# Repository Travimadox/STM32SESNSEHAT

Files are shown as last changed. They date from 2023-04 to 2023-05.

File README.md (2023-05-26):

# Imperium Environmental Monitoring HAT

The Imperium Environmental Monitoring HAT is a cutting-edge hardware accessory designed for use with STM32 microcontrollers. It is tailored for environmental monitoring and equipped with high-precision sensors for temperature and light. This allows for accurate data collection in various applications, including weather monitoring, room temperature monitoring, and greenhouse monitoring, providing invaluable insights into environmental conditions.

ImperiumSenseHAT
## Features

- High-precision sensors for temperature, humidity, atmospheric pressure, and light
- Seamlessly integrates into various systems
- Customizable to fit the needs of each user
- Easily programmable for extra functionality
- Affordable and reliable

## Usage

The Imperium Environmental Monitoring HAT can be used for a variety of purposes, including:

- Weather monitoring
- Room temperature and humidity monitoring
- Greenhouse monitoring

In addition, the sensor data can be used to make critical decisions about controlling external devices, such as triggering a fan or heater, to maintain a comfortable environment.

## Getting Started

To get started with the Imperium Environmental Monitoring HAT, simply connect it to your STM32 microcontroller using the provided pins. Then, download our library and follow the included instructions to begin collecting data.
- Hello World version of our board can be found here: [Hello World](HELLOWORLD.md)
- Detailed set-up instructions can be found here: [Setup](SESNSEHATSETUP.md)

## Customization

The Imperium Environmental Monitoring HAT is easily programmable, allowing the end user to add extra functionality to suit their specific needs. The provided libraries in the firmware folder includes examples of how to use the sensors.

## Cost

At Imperium, we pride ourselves on providing innovative and cost-effective solutions. Our HAT is a reliable and affordable option for anyone looking to monitor and control environmental conditions, whether in a commercial or personal setting.

## Support

If you have any questions or issues with the Imperium Environmental Monitoring HAT, please contact our support team at imperiumuct@gmail.com.

## License

This project is licensed under the [MIT License](LICENSE).

© 2023 Rumbizdai Mashumba, Phomolo Makina, and Travimadox Webb.

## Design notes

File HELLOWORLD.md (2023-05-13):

# STM32 ENVIRONSENSING HAT: Hello World Version

This program is designed to read data from temperature sensors and an analog light sensor, timestamp the data, and transmit it over UART to a terminal.

## Hello World Set Up Instructions

### Step 1: Hardware and Software Setup
For an in-depth guide on how to setup your hardware and software, kindly visit this link: [Setup Guide](SESNSEHATSETUP.md).

### Step 2: Download the HelloWorld Drivers
You can find and download the necessary HelloWorld drivers for this project from the following link: [HelloWorldDrivers](https://github.com/Travimadox/STM32SESNSEHAT/blob/main/Firmware/SENSEHATHELLOWORLD.zip)

### Step 3: Import the Project into STM32 CubeIDE
If you're unsure of how to import the project, refer to the following guides:
- [Imperium: Importing projects into STM32CubeIDE workspace - Step 3](https://github.com/Travimadox/STM32SESNSEHAT/blob/main/SESNSEHATSETUP.md)
- [Fastbitlab: Importing projects into STM32CubeIDE workspace](https://fastbitlab.com/microcontroller-embedded-c-programming-importing-projects-in-to-stm32cubeide-workspace/)

### Step 4: Build, Debug, and Flash the Project
Build and debug the project, then flash it onto the microcontroller. Remember to set the time and date at the beginning.

### Step 5: Setup Software Terminal Emulator
Open your software terminal emulator and ensure the settings match the UART settings in the hello world project. When everything is set up correctly, you should see output resembling the one below:

Hello World Output

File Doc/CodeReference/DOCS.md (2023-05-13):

# Code Reference

A web version of the doxumentation can be found here: [Imperium-STM32-SenseHat-Code-Reference](https://imperiumstm32hatdocs.tiiny.site/index.html)

A more detailed version of the documentation can also be found here: [Imperium-STM32-SenseHat-Code-Reference-Detailed](https://gleaming-capybara-68341f.netlify.app/files.html)
)

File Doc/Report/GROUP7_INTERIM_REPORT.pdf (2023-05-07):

## IMPERIUM

## STM32SenseHAT

### Title – STM32SenseHAT Report [EN]

Authors:

Rumbizdai Mashumba
Phomolo Makina
Travimadox Webb

MSHRUM006@myuct.ac.za
MKNPHO002@myuct.ac.za
WBBTRA001@myuct.ac.za

### Group 7 ♣

SenseHAT | Imperium

## Contents

1 Executive Summary | 3
2 Introduction | 3
3 Specifications | 5
4 Power Budget | 16
5 Design Process | 18
6 Conclusion | 19
Group7 | 1 | EEE3088F

Appendices | 21

## List of Tables

1 | Specifications of Battery Charger Submodule | | 5
2 | Specifications of the Battery protection submodule | | 6
3 | Specifications of the Voltage Regulator Submodule | | 7
4 | Specifications of the Microcontroller Board | | 9
5 | Specifications of the EEPROM | 10
6 | Specifications of the USB-UART Interface | 11
7 | Specifications of the Temperature Sensor | 13
8 | Specifications of the Light Sensor | 13
9 | Specifications of the Light-Dependent Resistor | 14
10 | Power Module Power Pudget | 16
11 | Microcontroller Module Power Budget | 17
12 | Sensing Module Power Budget | 17
13 | SenseHAT Power Consumption | 17

## List of Figures

1 | SenseHAT Block Diagram | | 4
2 | Power Submodule Schematic | | 8
3 | MCU Module Schematic | 12
4 | Sensing Module Schematic | 15
Group7 | 2 | EEE3088F

## 1 Executive Summary

The STM32 EnviroSensing HAT is a sophisticated, multi-purpose sensing system designed to accurately measure, log, and transmit various environmental parameters. The system comprises three primary modules: Power, MCU, and Sensing, each of which is meticulously designed to ensure optimal performance and seamless integration.
The Power module controls the MCU and sensors’ battery management, voltage regulation, and power distribution. It comprises a lithium-ion battery charger submodule that uses the TP4056 chip for precise charging control, a battery protection submodule incorporating the DW01 protection IC and dual MOSFETs for overcharge, over-discharge, and short-circuit protection, and a voltage regulator submodule utilizing the MCP1700T-3302ETT linear regulator for efficient voltage conversion.
The MCU module, built around the powerful and energy-efficient STM32F030F051C6T6 microcontroller, serves as the core processing unit. It is accompanied by an EEPROM (AT24C32) for non-volatile data storage, and multiple communication interfaces, including I2C, SPI, and UART, for seamless sensor data retrieval and transmission.
The Sensing module employs three high-precision sensors for direct interaction with the environment: a TMP102 temperature sensor with ±0.5°C accuracy and 12-bit resolution, an LTR-303-ALS digital light sensor providing 0.01 lux to 64k lux dynamic range with a 16-bit ADC, and an LDR (Light Dependent Resistor) for measuring ambient light levels. These sensors are carefully selected to ensure accuracy and compatibility with the overall system.

## 2 Introduction

### 2.1 SenseHat Concept

The STM32 EnviroSensing HAT is a custom-designed, innovative solution that accurately and responsively senses environmental conditions in various applications, including home environmental monitoring, greenhouse climate control, and industrial automation systems. By incorporating both temperature and light monitoring capabilities, this advanced HAT (Hardware Attached on Top) empowers users to effectively manage and regulate critical parameters. Seamlessly integrating temperature monitoring with ambient light sensing functionality, the STM32 EnviroSensing HAT ensures comprehensive environmental data collection. This combination of features is particularly useful in scenarios where maintaining optimal conditions is crucial, such as providing the perfect growing environment in a greenhouse. Additionally, the system can be implemented in smart home applications, offering adaptive temperature and lighting control based on real-time environmental data.
Key Sensor Specifications include a temperature sensor with a resolution of 0.0625, an accuracy of 0.5%, and a measurement range of -40°C to 125°C. The ambient light sensor boasts a 16-bit ADC resolution, an accuracy of 2%, and a detection range from 0.1 lux to 64k lux. The HAT is powered by a 5V bus for battery charging and a 3.3V bus to supply power to the MCU and sensors. Communication interfaces include I2C for effortless sensor and EEPROM communication with the STM32 and UART for efficient data transmission to the host computer. Data logging is a significant feature of the STM32 EnviroSensing HAT, with a consistent format that allows for easy analysis and integration into other systems. The logged data can
Group7 | 3 | EEE3088F

trigger user-defined threshold-based actions such as temperature and light regulation, further enhancing the device’s functionality.
In summary, the STM32 EnviroSensing HAT is a reliable and versatile environmental monitoring and control solution, making it ideal for a wide range of applications that require accurate and responsive sensing of temperature and light conditions.

### 2.2 Block Diagram

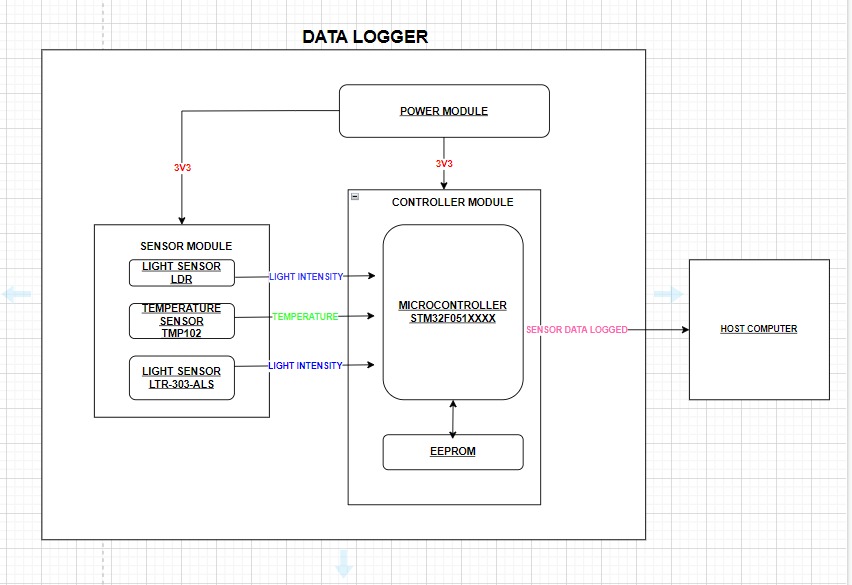
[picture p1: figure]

Figure 1: SenseHAT Block Diagram

Group7 | 4 | EEE3088F

## 3 Specifications

### 3.1 Power Module

The power module is designed to handle battery management and supply a stable 3.3V power source to all sensors and the MCU module from a 5V input provided by a USB bus.

### 3.1.1 Battery Charger Submodule

The battery charger submodule is responsible for managing the charging process for the 18650 battery. The specifications for this submodule are as follows: The chip used:TP4056

Table 1: Specifications of Battery Charger Submodule

Specification | Description/Detail
Input Voltage | VCC: 0.3-10 V TEMP,CE: 0-10 V
Charging current | 1000mA
Charge Voltage | 4.2V
Accuracy | 1.5%
Trickle Charge threshold | 2.9V
BAT Short Circuit duration | Continuous
BAT pin current | 1200mA
PROG pin current | 120uA
Operating Temperature | -45-85°C
Charge Status | Charging: RED LED-ON, GREEN-OFF Charge Termination: RED LED-OFF, GREEN-ON

Design Notes

1. Package: SOP-8
2. Rprog of 10k was used thus ibat is 130mA. This might be improved by changing the Rprog.
Group7 | 5 | EEE3088F

### 3.1.2 Battery protection submodule

This module protects the battery from under voltage, overvoltage, overcharging and overcurrent. Specifications are shown below: The chip used:DW01A

Table 2: Specifications of the Battery protection submodule

Specification | Detail
Input Voltage | 0.3-10V
Supply current | 3.0-6uA
OC output pin voltage | -24-0.3V
OD Output Pin Voltage | -0.-0.3V
CS Input pin voltage | -24-0.3V
Operating temperature range | -40-85°C
Starting charger Volatge | 1.2V
Overcharge Protection Voltage | 4.25-4.35V
Overcharge Release Voltage | 4.05-4.15V
Over-discharge Protection Voltage | 2.40-2.60 V
Overcurrent Protection Voltage | 130-170mV
Short current protection Voltage | 0.82-1.75V
Overcharge delay time | ”Typ:100ms Max 200ms”
Over-discharge delay time | ”Typical 55ms Maximum 200ms”
Overcurrent Delay Time | ”Typical 7ms Maximum 20ms”

Design Notes

1. Package: SOT-23-6
Group7 | 6 | EEE3088F

### 3.1.3 Voltage Regulator Submodule

This module regulates 5V from the USB bus/battery to 3.3V, suitable for the MCU and sensor module. Its specifications are shown below: The chip used:MCP1700T-3302ETT

Table 3: Specifications of the Voltage Regulator Submodule

Specification | Detail
Input Voltage | 2.3-6V
Input Quiescent Cur-rent | 1.6uA
Maximum Output Current | 250mA
Output Short Circuit Current | 408mA
Output Voltage Regu-lation | ”Min VR - 3.0%, VR - 2.0% Typ VR ± 0.4%, Max VR + 3.0%, VR + 2.0%”
VOUT Temperature Coefficient | 50 ppm/°C
Line Regulation | ”Min -1.0%, Typ 0.75%, Max 1%”
Load Regulation | ”Min -1.5%, Typ 1%, Max 1.5%”
Dropout Voltage | 350mV
Output Noise | 3 µV/(Hz)1/2
Power Supply Ripple Rejection Ratio | 44dB
Thermal Shutdown Protection | 140°C

Design Notes

1. Package: SOT-23-6
2. Voltage Regulator (VR): 3.3V
3. The internal power dissipation of the MCP1700 voltage regulator is a function of input voltage, output voltage, and output current. The power dissipation from the quiescent current draw is negligible, given its low value of 1.6 µA multiplied by the input voltage (VIN). The following equation can be employed to calculate the internal power dissipation of the LDO:1.6µA × VIN
Group7 | 7 | EEE3088F

### 3.1.4 Schematic

Link:https://github.com/Travimadox/STM32SESNSEHAT/blob/main/PCB/STM32SENSEHAT/power.kicad_sch (https://github.com/Travimadox/STM32SESNSEHAT/blob/main/PCB/STM32SENSEHAT/power.kicad_sch)

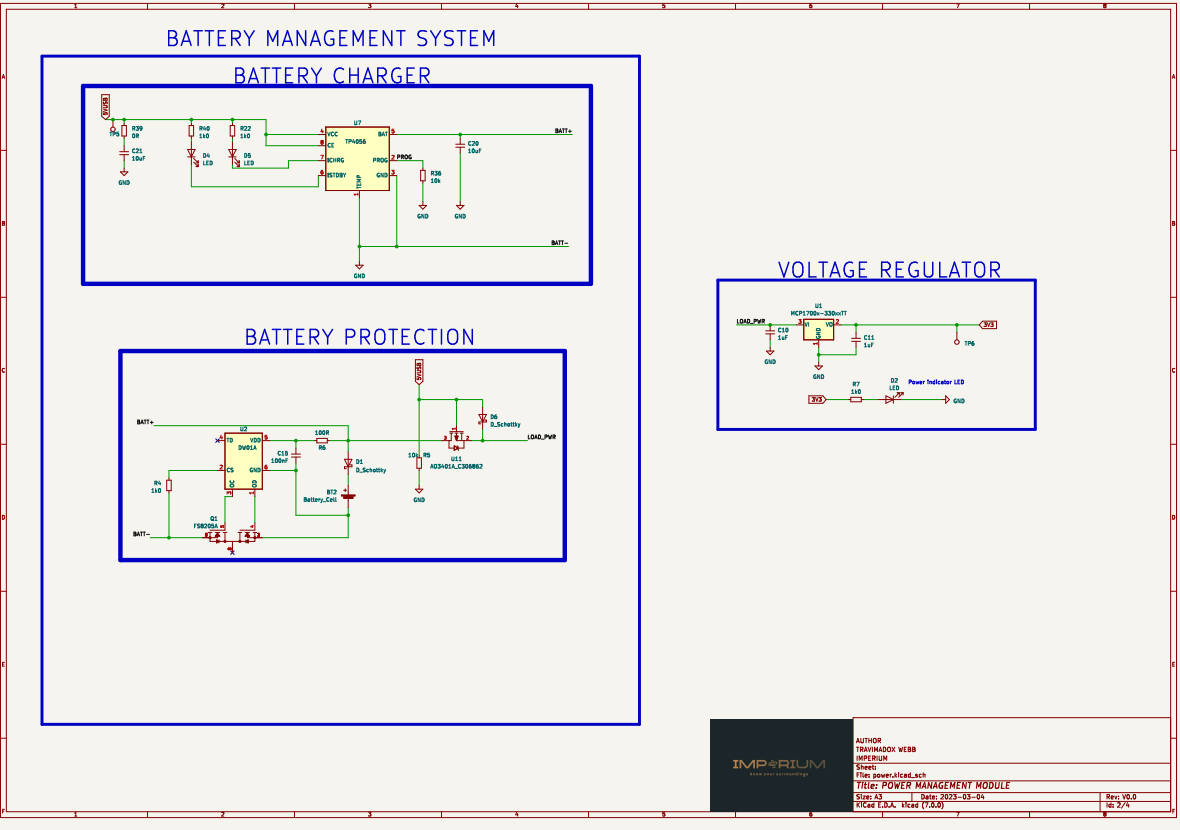
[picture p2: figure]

Figure 2: Power Submodule Schematic

### 3.1.5 Fit to Requirements

The current design meets the project requirements; however, there is potential for enhancements, particularly in the battery protection aspect. One possible improvement is modifying the battery charging mechanism. Adjusting the Rprog resistor can increase the charging current, eliminating the need to disconnect the battery when the USB is connected. This modification could streamline the charging process and provide a more user-friendly experience. Exploring this option and implementing it in future iterations of the STM32 EnviroSensing HAT could lead to a more refined and efficient design.

Group7 | 8 | EEE3088F

### 3.2 Microcontroller Module

The microcontroller interfacing submodule manages the communication between the microcontroller and the other components of HAT. It uses an STM32F0 microcontroller as the core processing unit, providing stable and efficient performance.

### 3.2.1 Microcontroller submodule

Its specifications are shown below: The chip used:STM32F051C6T6

Table 4: Specifications of the Microcontroller Board

Specification | Detail
Input Voltage Range | 2.6V- 3.3V
Standard Operational Voltage | ”Minimum: 2V Maximum: 3.6V”
External main voltage supply | ”Minimum: -0.3V Maximum: 4.0V”
Backup Operational Voltage | ”Minimum: 2.4V Maximum: 3.6V”
Input current | ”Minimum- 0.5 uA Maximum-5mA”
MCU Family | STM32F051C6TX
External memory | Include an EEPROM to store data from sensors
Real-time clock | Includes an RTC for timestamping data
Internal Clock Frequency | Typically: 8MHz
Data logging | Automatically logs data when USB is plugged into a computing device, with specified transmission times and time-outs in case of sensor errors or missed data
Sensor interface | Interfaces with digital sensors through I2C and ADCs with GPIO pins
Operating Temperature | ”Minimum- -40°C Maximum- 105 oC”
Storage Temperature Range | -65°C to 150°C
Flash Memory | 32 KB
RAM | ”32 KB Includes flash memory”
Clock Speed | Minimum- 48 MHz
Supported communication proto-cols | MCU should have interfaces of UART, I2C or SPI
Group7 | 9 | EEE3088F

Design notes

1. Package: LQFP48
2. The MCU in the STM32 EnviroSensing HAT is designed with additional headers to facilitate connections with external devices not included on the board. This feature provides increased flexibility and expandability, enabling users to interface with various peripherals for extended functionality and customisation options.

### 3.2.2 Memory Module

The AT24C256C-SSHL-T EEPROM is utilised in the STM32 EnviroSensing HAT for reading and writing logged data. This memory module’s specifications ensure efficient data storage and retrieval, catering to the project’s requirements. The following are the key specifications of the AT24C256C-SSHL-T EEPROM:

Table 5: Specifications of the EEPROM

Specification | Detail
Input Voltage | 1.7-5.5V
Supply Current | ”Typ 1mA Max 2mA”
Standby current | ”Typ 1uA Max 6uA”
Interface | I2C
Compatibility | 400kHz (1.7V) and 1MHz (2.5V, 2.7V, 5.0V)
Page Size | 64-byte
Pages | 512
Endurance | 1,000,000 write cycles
Data retention | 40 years
Operating temperature | 55°C to +125°C
DC Output Current | 5.0mA
Self-timed write cycle | 5ms

Design Notes

1. Package: SOIC-8
2. The address of the EEPROM in the STM32 EnviroSensing HAT is set to the default configuration, as pins A0, A1, and A2 are grounded. Zero-ohm resistors are connected to the communication lines as a mechanism for error handling, enabling the lines to be disconnected in case of unprecedented errors. This design aspect ensures flexibility in addressing potential issues related to data transmission within the EnviroSensing HAT.
Group7 | 10 | EEE3088F

### 3.2.3 Communications with Host Computer

The FT234 chip is incorporated in the STM32 EnviroSensing HAT to manage data transmission between the board and the host computer. This FTDI chip transmits logged data to the user, ensuring efficient and reliable communication. The key specifications of the FT234 chip are as follows:

Table 6: Specifications of the USB-UART Interface

Specification | Detail
Input Voltage | 5V
Data transfer rate | 300 baud to 3 Mbaud
UART interface | ”7 or 8 data bits, 1 or 2 stop bits and odd / even / mark/space / no parity UART signal inversion option *Synchronous and asynchronous bit bang interface options with RD# and WR# strobes.”
Driver Support | ”Royalty-free VIRTUAL COM PORT (VCP) DRIVERS Royalty-free D2XX Direct Drivers (USB Drivers + DLL S/W Interface) Refer to http://www.ftdichip.com/Documents/InstallGuides.htm” (http://www.ftdichip.com/Documents/InstallGuides.htm)
Operating Tempera-ture (Power Applied) | -40°C to 85°C
VCC Supply Voltage | -0.3 to +5.5
VCCIO IO Voltage | 0.3 to +4.0
DC Input Voltage – USBDP and USBDM | -0.5 to +3.63
DC Output Current – Output | 22mA
Data Retention | 10 years
Write Cycle | 2000 cycles
Read Cycle | Unlimited Cycles

Design Notes

1. Package: DFN-12
2. The STM32 EnviroSensing HAT utilises a USB self-powered configuration for a reliable power supply. A ferrite bead is incorporated to mitigate electromagnetic interference (EMI) and enhance signal integrity. These design aspects contribute to the HAT’s efficient operation and performance stability.
Group7 | 11 | EEE3088F

### 3.2.4 Schematic

Link:https://github.com/Travimadox/STM32SESNSEHAT/blob/main/PCB/STM32SENSEHAT/mcu.kicad_sch (https://github.com/Travimadox/STM32SESNSEHAT/blob/main/PCB/STM32SENSEHAT/mcu.kicad_sch)

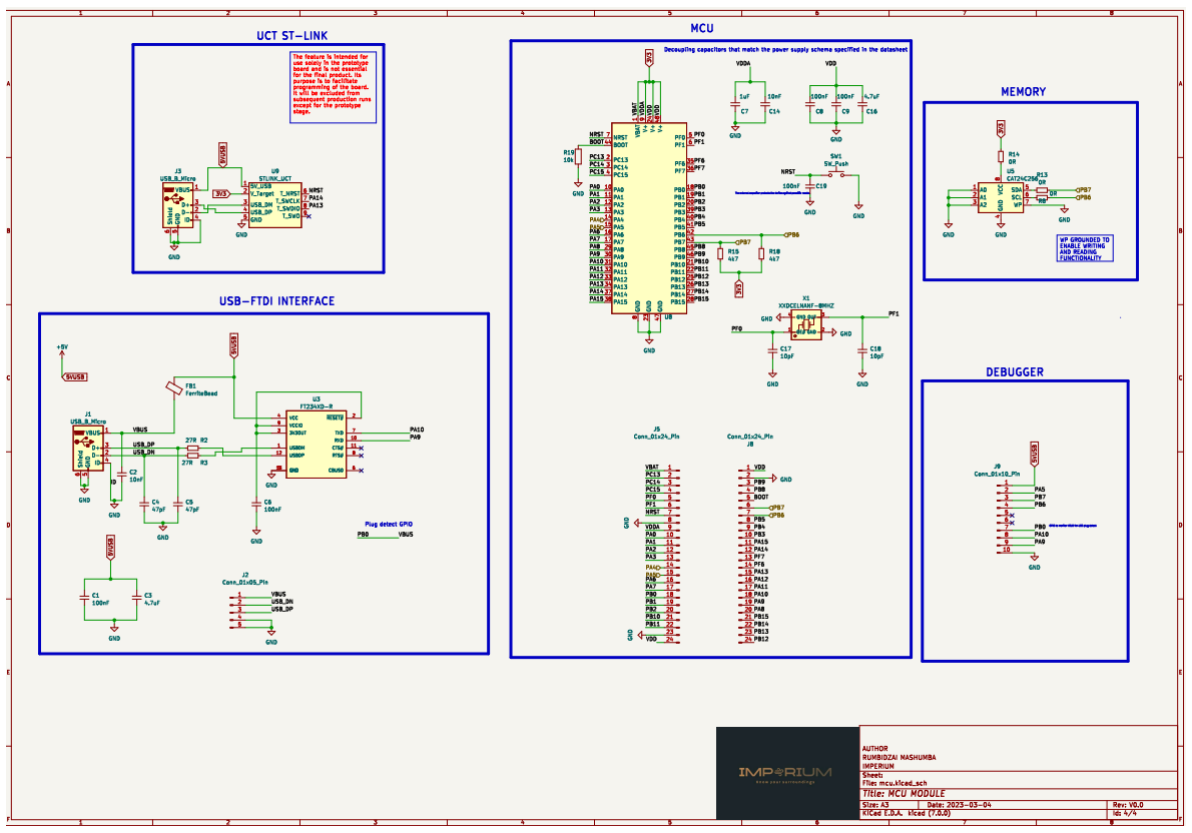
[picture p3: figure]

Figure 3: MCU Module Schematic

### 3.2.5 Fit to Requirements

The current design of the MCU module meets the basic requirements set forth by the client. However, several improvements can be considered for future iterations. For example, replacing the EEPROM with a higher-capacity variant or configuring the memory to use an SD card would enable longer data logging periods. Integrating an ESP32 module could also provide network connectivity for wireless data transmission and battery-level alerts. Furthermore, incorporating a dedicated CMOS battery for the internal RTC in the STM32 would prevent loss of time settings in the event of power loss. These enhancements would further refine the MCU module and expand its capabilities.

Group7 | 12 | EEE3088F

### 3.3 Sensing Module

Responsible for interacting with the environment directly and sensing environmental data

### 3.3.1 Temperature sensor

The temperature sensor used is TMP102. Its specifications are:

Table 7: Specifications of the Temperature Sensor

Specification | Details
Input Voltage | 3.3V
Range | –40°C to 125°C
Accuracy (tempera-ture error) | ”–25°C to 85°C ±0.5 –40°C to 125°C ±1”
Resolution | 0.0625
Operating tempera-ture | –55°C to 150°C
Interface | ”I2C Supports High Speed and Fast Mode”

Design Notes

1. Package: SOT-563
2. The alert pin is not connected in the current schematic, which may constrain certain chip functionalities. However, this design choice’s core purpose of temperature measurement remains unaffected. Future iterations could consider wiring the alert pin to enhance the chip’s overall capabilities without compromising the basic functionality.

### 3.3.2 Light Sensor

The sensor used is the LTR-303-ALS. The specifications are as follows:

Table 8: Specifications of the Light Sensor

Specification | Details
Input Voltage | 3.3V
Operating tempera-ture | –30°C to 70°C
Full dynamic range | 0.01lux-64k lux
Effective Resolution | 16 bits
Interface | ”I2C Supports fast Mode”
Group7 | 13 | EEE3088F

Design Notes

1. Package: SOT-363
2. In the current schematic, the alert pin is not connected, potentially limiting some of the chip’s features, though the basic functionality of ambient light measurement remains unaffected. The power pin of this chip is designed to be connected to Vcc only in the event of a TMP102 sensor failure. It should be noted that the sensor accuracy for this particular component is not explicitly stated in the datasheet. Future design iterations may address these aspects to optimize the chip’s functionality.

### 3.3.3 LDR

An LDR (light-dependent resistor) has been incorporated into the design to supplement the digital light sensor, enhancing the system’s overall light-sensing capabilities. The specifications of the LDR are as follows:

Table 9: Specifications of the Light-Dependent Resistor

Specification | Details
Input Voltage | ”Typical:3.3V Maximum:10V”
Maximum Power Dissipation | 90mW
Ambient Temperature | -30°C to 70°C
Spectral Peak | 540nm
Light resistance | 10-20k Ω
Dark resistance | 2MΩ
Gamma Value | 0.7
Response Time | ”Rise Time: 30ms Decay Time:30ms”

Design Notes

1. The LDR employed in this design is a basic photoresistor, specifically, the model widely used in the first-year practicals of the EEE1006F course at the University of Cape Town. Utilising a familiar and accessible LDR, the design aims to leverage the team’s existing knowledge and experience, ensuring ease of implementation and compatibility with other components.
Group7 | 14 | EEE3088F

### 3.3.4 Schematic

Link::https://github.com/Travimadox/STM32SESNSEHAT/blob/main/PCB/STM32SENSEHAT/sensor.kicad_sch

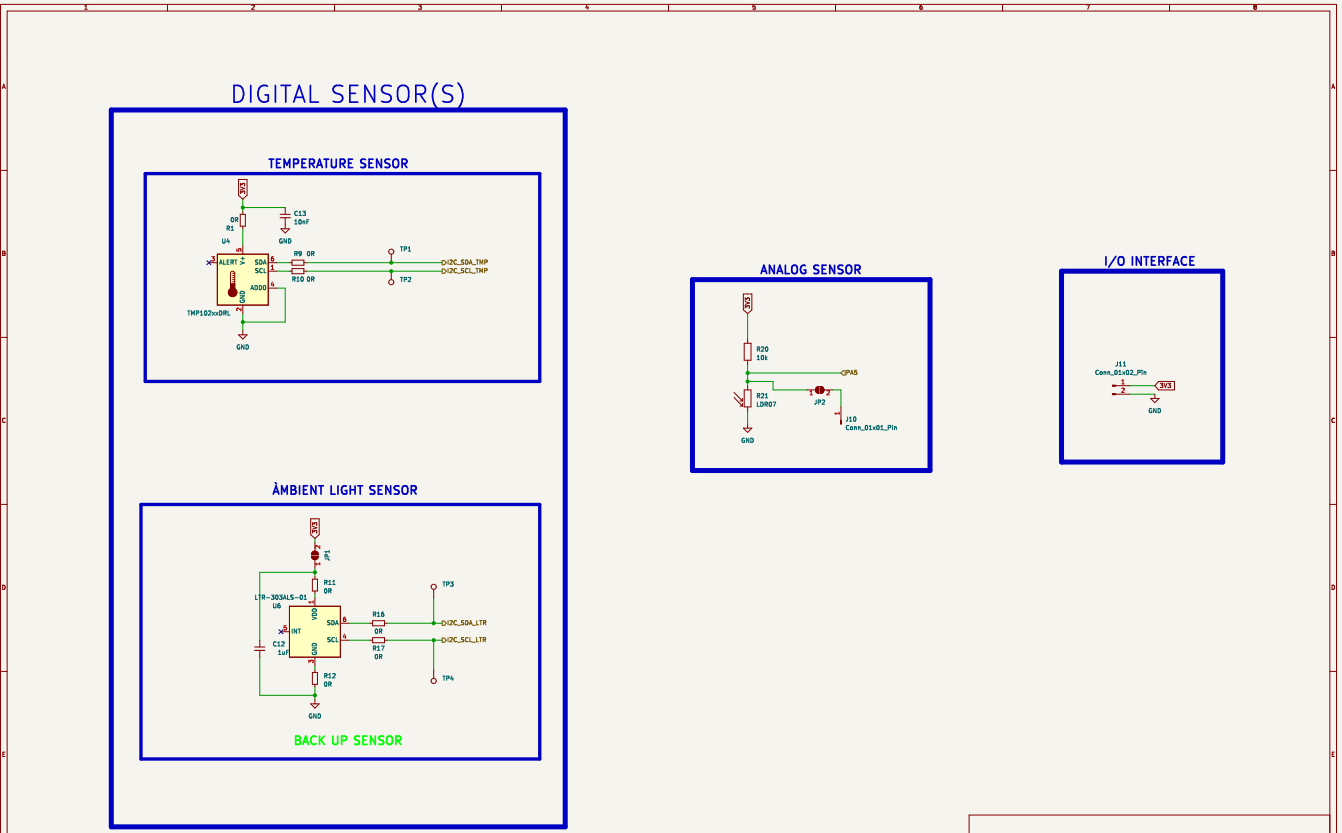
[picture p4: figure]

Figure 4: Sensing Module Schematic

### 3.3.5 Fit to Requirements

The current sensor configuration is suitable for the specified use cases; however, potential modifications could be considered for expanding functionality. Although the analog LDR may exhibit limited sensitivity (approx. 100 lux) and accuracy (±10%), it is sufficient for this board’s intended applications, such as basic ambient light monitoring. For higher lux ranges, the digital light sensor (LTR-303 ALS) with a range of 0.1 lux to 64,000 lux and an accuracy of ±2% should be utilised. The decision to leave the alert pins of the digital sensor unconnected also limits the sensor’s capabilities, such as interrupt-based alerts. Furthermore, the sensors remain powered on even when not recording data, leading to unnecessary power consumption, which could be up to 10% of the total power budget. Addressing this concern and implementing power-saving strategies, such as sleep mode or power gating, will be a priority in the next iteration of the board design—the board’s efficiency and overall performance.

Group7 | 15 | EEE3088F

## 4 Power Budget

### 4.1 Power Module

Table 10: Power Module Power Pudget

Component | Supply
| Voltage | Minimum
| | Current | Typical
| | | Current | Maximum
| | | | Current | Minimum
| | | | | Power | Typical
| | | | | | Power | Maximum
| | | | | | | Power
TP4056 | 5 | 0.95 | 1 | 1.05 | 4.75 | 5 | 5.25
DW01A | 3.6 | 0.000003 | 0.000003 | 0.000006 | 0.0000108 | 0.0000108 | 0.0000216
MCP1700X-330XXTT | 5 | 0.000016 | 0.000016 | 0.000004 | 0.00008 | 0.00008 | 0.00002
Resistors | | | | | 1 | 1 | 1
| | | | Total Power | 5.7500908 | 6.0000908 | 6.2500416

Notes:

1. For the DW01A and MCP1700X-330XXTT, minimum current values were not provided in the datasheets. Therefore, the typical current values were used in their place.
2. The power budget accounts for 8 resistors, each with a power rating of 125mW, for a total power dissipation of 1W.
3. Capacitors were not included in the power budget, as their power consumption was approximated to be negligible.
4. The ferrite bead is not included in the power budget. However, based on its specifications (300mA, 68nH ± 5%, 850mΩ, 0603 SMD, ROHS), its power consumption can be approximated using P = I

2R, where I is the current and R is the resistance.

5. The AO3401A MOSFET was not included in the power budget due to insufficient information in the datasheet. However, its rated specifications (20V, 6A, 1.5W, 23mΩ@4.5V) can be used to approximate power consumption using P = I

2R, where I is the drain
current and R is the on-resistance at the specified gate voltage.
6. The Schottky diode was not included in the power budget, as there was no direct power consumption information provided in the datasheet. However, based on its specifications (30V, 800mV@100mA, 200mA, SOT-23, ROHS), its power consumption can be estimated using P = IV , where I is the forward current and V is the forward voltage drop. Additionally, reverse recovery characteristics can be considered for dynamic power estimation.
Group7 | 16 | EEE3088F

### 4.2 Microcontroller Module

The power budget for the microcontroller interfacing module is shown below:

Table 11: Microcontroller Module Power Budget

Component

Supply
Voltage
(nominalV)

Minimum
Current

Typical
Current

Maximum
Current

Minimum
Power

Typical
Power

Maximum
Power
STM32F051C6T6 | 3.3 | 0.05 | 0.1 | 0.1 | 0.165 | 0.33 | 0.33
FT234XD-R | 3.3 | 0.0065 | 0.008 | 0.0083 | 0.02145 | 0.0264 | 0.02739
CAT24C256 | 3.3 | 0.001 | 0.001 | 0.002 | 0.0033 | 0.0033 | 0.0066
Resistors | | | | | 1 | 1 | 1
| | | | Total Power | 1.18975 | 1.3597 | 1.36399

Notes:

1. The power budget accounts for 8 resistors, each with a power rating of 125mW, for a total power dissipation of 1W.

### 4.3 Sensing Module

The power budget for the sensing module is shown below:

Table 12: Sensing Module Power Budget

Component

Supply
Voltage
(nominalV)

Minimum
Current

Typical
Current

Maximum
Current

Minimum
Power

Typical
Power

Maximum
Power
TMP102XXDRL | 3.3 | 0.000001 | 0.00001 | 0.00001 | 0.0000033 | 0.000033 | 0.000033
LTR-303ALS-01 | 3.3 | 0.000005 | 0.00022 | 0.00022 | 0.0000165 | 0.000726 | 0.000726
Resistors | | | | | 1 | 1 | 1
| | | | Total Power | 1.0000198 | 1.000759 | 1.000759

Notes:

1. The power budget accounts for 8 resistors, each with a power rating of 125mW, for a total power dissipation of 1W.

### 4.4 System Total

The system power budget is shown below:

Table 13: SenseHAT Power Consumption

Submodule | Minimum
| Power | Typical
| | Power | Maximum
| | | Power
Power Module | 5.7500908 | 6.0000908 | 6.2500416
Sensing Module | 1.0000198 | 1.000759 | 1.000759
MCU Module | 1.18975 | 1.3597 | 1.36399
Total | 7.9398606 | 8.3605498 | 8.6147906
Group7 | 17 | EEE3088F

## 5 Design Process

The design process for the STM32 EnviroSensing HAT was characterised by several critical decisions and inflexion points that ultimately shaped the final product. This section describes these vital moments, the rationale behind each choice, and supporting details and numbers.

### 5.1 Selection of Microcontroller

The STM32F051C6T6 was selected as the primary microcontroller due to its availability during design. This ARM Cortex-M0-based MCU features 32KB Flash memory, 4KB SRAM, and a 48MHz maximum frequency, ensuring compatibility with other microcontrollers from the same family if needed in the future.

### 5.2 Sensor Selection

Initially, the BME280 sensor was considered for its compactness and rich feature set. However, due to budget constraints, we opted for the more affordable TMP102 ($1.50/unit) and LTR-303 ALS ($0.65/unit) sensors as alternatives to the BME280 ($3.00/unit). This decision led to a slight reduction in accuracy compared to the BME280. It resulted in the loss of approximately 10% of the available board space, necessitating adjustments in the overall layout and component placement.

### 5.3 Choice of Power Supply Regulator

We selected Texas Instruments’ MCP1700 low-dropout (LDO) linear regulator for our design, considering its compatibility with our 5V supply, budget constraints, and performance requirements. The MCP1700 delivers a stable 3.3V output at up to 250mA with an input voltage range of 2.7V to 6V, providing a 1V headroom for voltage fluctuations. To ensure the MCP1700’s proper thermal performance, we calculated power dissipation and evaluated the junction-to-ambient thermal resistance, verifying that the maximum junction temperature would not be exceeded during operation. This approach allowed us to implement the MCP1700 effectively, meeting our project’s technical and budgetary requirements.

### 5.4 Data Storage and Retrieval

A 512KB (4Mbit) EEPROM, such as the CAT24C256 by Atmel, was utilised as the only available option for data storage during the design process. This capacity limits data collection to approximately two days before the EEPROM becomes full, assuming a data logging rate of one sample per second. Another reason for choosing the CAT24C256 was its low cost, at just $0.50 per unit, which further contributed to meeting the project’s budget constraints.

### 5.5 Communication Protocols

I2C was chosen as the primary communication protocol due to the team’s familiarity with I2C devices, facilitating firmware development. The FTDI FT234XD-R UART bridge chip was selected for data transmission to the host computer because of previous experience with the

Group7 | 18 | EEE3088F

component and project requirements. The FT234XD-R supports data transfer rates of up to 3 Mbaud, ensuring efficient communication between the STM32 EnviroSensing HAT and the host computer.

### 5.6 PCB Layout and Design

The PCB layout was iteratively improved to minimise signal interference, reduce electromagnetic noise, and enhance manufacturability. Critical component placement and proper heat dissipation were prioritised, utilising thermal vias and copper pour areas. The final PCB dimensions were 100mm x 100mm.

### 5.7 Testing and Debugging

Several simulations were performed to ensure the robustness of the design, including schematic Design Rule Checks (DRCs) and sensor testing with breakout boards, breadboards, and the STM32 microcontroller to validate the concept in real-world conditions. The testing involved measuring temperature and light levels under various environmental conditions to ensure accuracy and reliability.

### 5.8 ST-Link Inclusion

The decision to include the ST-Link debugger was debated until the last minute, and it was ultimately incorporated into the prototype board. The ST-Link V2 debugger has an SWD interface.

## 6 Conclusion

In conclusion, the STM32 EnviroSensing HAT is a highly capable and efficient board providing an excellent environmental sensing application platform. The current design meets the client’s basic requirements, and there is potential for further enhancements to expand the board’s capabilities.
The power module, battery charger submodule, battery protection submodule, voltage regulator submodule, MCU module, memory module, and sensing module have all been designed to meet the project’s specific requirements. The components’ specifications have been carefully considered to ensure optimal performance and efficient operation.
However, several areas for improvement have been identified in the design. For instance, modifying the battery charging mechanism by adjusting the Rprog resistor could streamline the charging process and provide a more user-friendly experience. Incorporating an ESP32 module could provide network connectivity for wireless data transmission and battery-level alerts. Power-saving strategies, such as sleep mode or power gating, could reduce unnecessary power consumption and enhance the board’s efficiency.
By refining these aspects and incorporating additional functionalities, the STM32 EnviroSensing HAT could become an even more capable platform for environmental sensing applications. The team is committed to further developing and refining the design, incorporating
Group7 | 19 | EEE3088F

user feedback and incorporating new technological advancements to ensure that the board remains a leading solution for environmental sensing.

Group7 | 20 | EEE3088F

# Appendices

Group7 | 21 | EEE3088F

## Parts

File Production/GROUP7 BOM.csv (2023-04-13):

Comment | Designator | Footprint | JLCPCB Part #
10nF | C2 | Capacitor_SMD:C_0805_2012Metric | C1710
1k0 | R22,R4,R7,R40 | Resistor_SMD:R_0805_2012Metric | C17513
USB_B_Micro | J1,J3 | footprints:USB_Conn_JLC_LCSC_C404969 | C404969
10uF | C20,C21 | Capacitor_SMD:C_0805_2012Metric | C15850
4k7 | R15,R18 | Resistor_SMD:R_0805_2012Metric | C17673
1uF | C12 | Capacitor_SMD:C_0805_2012Metric | C28323
27R | R2,R3 | Resistor_SMD:R_0805_2012Metric | C17594
MCP1700x-330xxTT | U1 | JLCfootprint:SOT-23-3_L2.9-W1.6-P1.90-LS2.8-BR | C39051
FT234XD-R | U3 | JLCfootprint:DFN-12_L3.0-W3.0-P0.45-BL-EP | C132158
4.7uF | C3 | Capacitor_SMD:C_0805_2012Metric | C1779
100nF | C1,C6,C15 | Capacitor_SMD:C_0805_2012Metric | C49678
FS8205A | Q1 | JLCfootprint:TSSOP-8_L4.4-W3.0-P0.65-LS6.4-BL | C5148694
AO3401A | U11 | JLCfootprint:SOT-23-3_L2.9-W1.3-P1.90-LS2.4-BR | C306862
CAT24C256 | U5 | JLCfootprint:SOIC-8_L4.9-W3.9-P1.27-LS6.0-BL | C6482
TMP102xxDRL | U4 | JLCfootprint:SOT-563_L1.6-W1.2-P0.50-LS1.6-BR | C99269
TP4056 | U7 | JLCfootprint:ESOP-8_L4.9-W3.9-P1.27-LS6.0-BL-EP | C382139
0R | R1,R16,R17,R39 | Resistor_SMD:R_0805_2012Metric | C17477
LTR-303ALS-01 | U6 | JLCfootprint:SOT-363_L2.0-W1.3-P0.65-LS2.1-BL | C364577
47pF | C4,C5 | Capacitor_SMD:C_0805_2012Metric | C14857
FerriteBead | FB1 | JLCfootprint:L0603 | C13415
10k | R5,R19,R20,R36 | Resistor_SMD:R_0805_2012Metric | C17414
100R | R6 | Resistor_SMD:R_0805_2012Metric | C17408
DW01A | U2 | JLCfootprint:SOT-23-6_L2.9-W1.6-P0.95-LS2.8-BL | C351410
XXDCELNANF-8MHZ | X1 | JLCfootprint:OSC-SMD_4P-L3.2-W2.5-BL | C518154
D_Schottky | D1,D6 | JLCfootprint:SOT-23-3_L3.0-W1.7-P0.95-LS2.9-BR | C47546

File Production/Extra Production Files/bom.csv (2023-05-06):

Designator | Footprint | Quantity | Value | LCSC Part #
BT2 | BatteryHolder_Keystone_1042_1x18650 | 1 | Battery_Cell
C1, C15, C6 | 805 | 3 | 100nF
C10, C11, C7 | C_Disc_D5.0mm_W2.5mm_P5.00mm | 3 | 1uF
C12 | 805 | 1 | 1uF
C13, C14 | C_Disc_D5.0mm_W2.5mm_P5.00mm | 2 | 10nF
C16 | C_Disc_D5.0mm_W2.5mm_P5.00mm | 1 | 4.7uF
C17, C18 | C_Disc_D5.0mm_W2.5mm_P5.00mm | 2 | 10pF
C19, C8, C9 | C_Disc_D5.0mm_W2.5mm_P5.00mm | 3 | 100nF
C2 | 805 | 1 | 10nF
C20, C21 | 805 | 2 | 10uF
C3 | 805 | 1 | 4.7uF
C4, C5 | 805 | 2 | 47pF
D1, D6 | SOT-23-3_L3.0-W1.7-P0.95-LS2.9-BR | 2 | D_Schottky
D2, D4, D5 | LED_D5.0mm | 3 | LED
FB1 | L0603 | 1 | FerriteBead
J1, J3 | USB_Conn_JLC_LCSC_C404969 | 2 | USB_B_Micro
J10 | PinHeader_1x01_P2.54mm_Vertical | 1 | Conn_01x01_Pin
J11 | PinHeader_1x02_P2.54mm_Vertical | 1 | Conn_01x02_Pin
J2 | PinHeader_1x05_P2.54mm_Vertical | 1 | Conn_01x05_Pin
J5, J8 | PinHeader_1x24_P2.54mm_Vertical | 2 | Conn_01x24_Pin
J9 | PinHeader_1x10_P2.54mm_Vertical | 1 | Conn_01x10_Pin
JP1 | SolderJumper-2_P1.3mm_Open_Pad1.0x1.5mm | 1 | SolderJumper_2_Open
JP2 | SolderJumper-2_P1.3mm_Open_RoundedPad1.0x1.5mm | 1 | SolderJumper_2_Open
Q1 | TSSOP-8_L4.4-W3.0-P0.65-LS6.4-BL | 1 | FS8205A
R1, R10, R11, R12, R13, R14, R16, R17, R39, R8, R9 | 805 | 11 | 0R
R15, R18 | 805 | 2 | 4k7
R19, R20, R36, R5 | 805 | 4 | 10k
R2, R3 | 805 | 2 | 27R
R21 | R_LDR_5.1x4.3mm_P3.4mm_Vertical | 1 | LDR07
R22, R4, R40, R7 | 805 | 4 | 1k0
R6 | 805 | 1 | 100R
SW1 | SW_PUSH_6mm | 1 | SW_Push
TP1, TP2, TP3, TP4, TP5, TP6 | TestPoint_Pad_D3.0mm | 6 | TestPoint
U1 | SOT-23-3_L2.9-W1.6-P1.90-LS2.8-BR | 1 | MCP1700x-330xxTT
U11 | SOT-23-3_L2.9-W1.3-P1.90-LS2.4-BR | 1 | AO3401A_C306862 | C306862
U2 | SOT-23-6_L2.9-W1.6-P0.95-LS2.8-BL | 1 | DW01A
U3 | DFN-12_L3.0-W3.0-P0.45-BL-EP | 1 | FT234XD-R
U4 | SOT-563_L1.6-W1.2-P0.50-LS1.6-BR | 1 | TMP102xxDRL
U5 | SOIC-8_L4.9-W3.9-P1.27-LS6.0-BL | 1 | CAT24C256
U6 | SOT-363_L2.0-W1.3-P0.65-LS2.1-BL | 1 | LTR-303ALS-01
U7 | ESOP-8_L4.9-W3.9-P1.27-LS6.0-BL-EP | 1 | TP4056
U8 | STM32F051C6T6 | 1 | ~
U9 | STLINK_UCT | 1 | STLINK_UCT
X1 | OSC-SMD_4P-L3.2-W2.5-BL | 1 | XXDCELNANF-8MHZ | C367183

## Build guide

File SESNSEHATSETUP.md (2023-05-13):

# Setting up the SENSEHAT for the first time.
## Requirements:
### 1.Hardware Requirements
To work with this repository, you will need the following hardware:

1. STM32SenseHat
2. STM32F051C6T6 Daughter Board
3. USB-A to Micro-USB cable
4. 4.2V 18650 Li-Ion battery
5. ST-LINK V2

Please ensure that you have all the necessary hardware before proceeding with the setup.

### 2.Software Requirements
The code in this repository has primarily been developed using the STM32CubeIDE. This is the recommended IDE for working with this codebase.

**Recommended IDE**: 

- STM32CubeIDE

However, the repository is also compatible with several other IDEs. If you are comfortable using an alternative IDE, please make sure to install the necessary plugins and extensions.

**Alternative IDEs**:

- Visual Studio Code: 
  You will need the following plugins:
    - [STM32 for VSCode by Bureau Moeilijke Dingen](https://marketplace.visualstudio.com/items?itemName=bmd.stm32-for-vscode)
    - [STM32 by STMicroelectronics](https://marketplace.visualstudio.com/items?itemName=stmicroelectronics.stm32-vscode-extension)
    
- Keil MicroVision: 
  You can download it [here](https://www.keil.com/)
  **Note**: This is a paid IDE,however a free version is also available.

Please note, the codebase is written in C. However, contributions in C++ or Embedded Rust are welcome.

**Software terminal emulator**

The examples provided here are based on the Tera Term ,however the other software terminal emulators should work too.
- Tera Term [Download](https://download.cnet.com/Tera-Term/3000-2094_4-75766675.html)
- Real Term [Download](https://realterm.sourceforge.io/index.html#downloads_Download)
- PuTTY [Download](https://www.putty.org/)
- KiTTY [Download](https://kitty.en.lo4d.com/windows)

## Setting up STM32 Peripherals:
To set up the STM32 peripherals check:[Setting up STM32 peripherals](https://github.com/Travimadox/STM32SESNSEHAT/blob/main/Firmware/STM32SETUP.md)

## STEP1. Powering and setting up the SENSEHAT hardware.
**CAUTION:** Ensure that the power source supplies at least 5V at 1A.

Follow this steps to set up you SENSEHAT.

  1. Connect the power source to the HAT via the USB cable.The LED should go on to indicate it is on.
  2. Place the 18650 battery in the battery holder and Let the battery charge for an hour, the green LED will go on when fully charged.
  3. Unplug the power supply and plug in the STM32F0 to the SENSEHAT as shown below.
  
  Connecting_STM32F0_to_SENSEHAT
  
## Step2. Include libraries to the SENSEHAT.
  1. Download and include the LDR files by following this [instructions](https://github.com/Travimadox/STM32SESNSEHAT/tree/main/Firmware).
  2. Download and include the TMP102 (temperature sensor) [files](https://github.com/Travimadox/STM32SESNSEHAT/tree/main/Firmware/TMP102) by following this [instructions](https://github.com/Travimadox/STM32SESNSEHAT/blob/main/Firmware/TMP102/Instructions.md).
  3. Download the [LTR303ALS file](https://github.com/Travimadox/STM32SESNSEHAT/tree/main/Firmware/LTR303ALS) and follow this [instruction](https://github.com/Travimadox/STM32SESNSEHAT/blob/main/Firmware/LTR303ALS/Instructions.md) to include them in your project.
  4. Download and include the RTC [files](https://github.com/Travimadox/STM32SESNSEHAT/tree/main/Firmware/RTC) by following this [instructions](https://github.com/Travimadox/STM32SESNSEHAT/blob/main/Firmware/RTC/Instructions.md).
  5. Download and include the AT24C256 (EEPROM) [files](https://github.com/Travimadox/STM32SESNSEHAT/tree/main/Firmware/AT24C256) by following this [instructions](https://github.com/Travimadox/STM32SESNSEHAT/blob/main/Firmware/AT24C256/Instructions.md).
## Step3: Test the Libraries(Optional).
  1. Download test [files](https://github.com/Travimadox/STM32SESNSEHAT/blob/main/Firmware/SENSEHATLIBTESTS.zip).
  2. Copy the file directory.
  
  Copying directory
  
  3. Go to file in the STM32cubeIDE, select "Open projects from file system".
  
  Opening project
  
  4. In the open dialogue, paste the file directory in the "import source" block.
  
  Pasting file directory
  5. Expand the Libraries folder>>SENSEHATEEPROMTEST>>core>>Src then open the main.c file.
  
  Opening main.c file
  
  6. Run the code!
  7. Follow the steps **2-to-6** above to test for other libraries.

## Step 4: Implementation of Sensehat Full Functionality
**Still being worked on**
  1. Connect the SENSEHAT to the PC via a USB cable. The debugger light should go on as shown below.
  
  Debugger
  
  2. Download the intergrating drivers here: [STM32SenseHatDriver](https://github.com/Travimadox/STM32SESNSEHAT/tree/main/Firmware/SENSEHAT).
  3. Open the files in STM32cubeIDE by following steps 2-to-5 in `Step3` above.
  4. Build and run the main.c file. You should see the debugger light flashing, wait till the following displays in console.
  
  Exit_message.
  
  5. Your SENSEHAT is now ready! You can disconnect and place it in the environment of you choice.

# FAQ
**Video to be uploaded soon**

Should you encounter problems while setting up your SENSEHAT, please visit our [FAQ](FAQ.md) or alternately watch the video on [How to setup SENSEHAT]().

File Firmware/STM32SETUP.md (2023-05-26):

# 1. Setting up an ADC Channel in STM32CubeIDE:

Follow these steps to set up an ADC channel for your project in STM32CubeIDE:

1. Open your project in STM32CubeIDE.
2. Click on the "Pinout & Configuration" tab, usually located at the bottom of the window.
3. Navigate to the "Analog" section in the left-hand menu.
4. Locate "ADC" and expand its options.
5. Select "Channel 5" and set the ADC mode to "Continuous Conversion Mode".
6. Save your configuration and generate the code.

For reference, you can refer to the image below, which shows the STM32CubeIDE interface with the proper ADC configuration:

STM32CubeIDE ADC Configuration

# 2. Setting up an I2C Channel in STM32CubeIDE:
## Setting up I2C channel
Follow these steps to set up an I2C channel for your project in STM32CubeIDE:

1. Open your project in STM32CubeIDE.
2. Click on the "Pinout & Configuration" tab, usually located at the bottom of the window.
3. Navigate to the "Connectivity" section in the left-hand menu.
4. Locate "I2C" and expand its options.
5. Enable I2C from the dropdown menu on the right.
6. For reference, you can refer to the image below:

STM32CubeIDE I2C Configuration

## Setting up System clock
Follow these steps to set up the system clock

1. Open your project in STM32CubeIDE.
2. Click on the "Pinout & Configuration" tab, usually located at the bottom of the window.
3. Navigate to the "System Core" section in the left-hand menu.
4. Locate "RCC" and expand its options then select High Speed Clock and choose source as Crystal Ceramic Oscillator.
5. For reference, you can refer to the image below:

STM32CubeIDE System Clock Configuration

# 4.Setting up RTC peripherals in STM32CubeIDE

## Setting up System clock
Follow these steps to set up the system clock

1. Open your project in STM32CubeIDE.
2. Click on the "Pinout & Configuration" tab, usually located at the bottom of the window.
3. Navigate to the "System Core" section in the left-hand menu.
4. Locate "RCC" and expand its options then select High Speed Clock and Low Speed Clock then choose source as Crystal Ceramic Oscillator.
5. For reference, you can refer to the image below:

STM32CubeIDE System Clock Configuration

## Setting the RTC Timer
Follow these steps to set up the RTC Timer:

1. Open your project in STM32CubeIDE.
2. Click on the "Pinout & Configuration" tab, usually located at the bottom of the window.
3. Navigate to the "Timers" section in the left-hand menu.
4. Locate "RTC" and expand its options then Activate clock source and calendar. No need to set the date and time as this catered for by the library functions.
5. For reference, you can refer to the image below:

STM32CubeIDE RTC TIMER Configuration

## Clock Configuration
Change the HCLK to 48MHz as shown below:

STM32CubeIDE Clock Configuration

# Step 5: .Setting up UART peripherals in STM32CubeIDE

Visit [Deep Blue Embedded](https://deepbluembedded.com/stm32-timers-tutorial-hardware-timers-explained/)

# Step 6: .Setting up Timer Interrupts in STM32CubeIDE

Visit [Deep Blue Embedded](https://deepbluembedded.com/stm32-usart-uart-tutorial/)

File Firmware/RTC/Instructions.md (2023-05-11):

# RTC Library Library Integration Guide

## Step 1:

 Download the `rtc.c` and `rtc.h` files from the provided source or from your own implementation.
## Step 2:

 Add the `rtc.c` file to your project's source folder and the `rtc.h` file to your project's include folder.
## Step 3: 

In your main program, add the following include statement to include the RTC library header file:
    
```c
#include "rtc.h"
```

## Step 4: 

Initialize the RTC module using STM32CubeIDE GUI. Configure RTC clock source and enable RTC in the main initialization code or in the Clock Configuration function (SystemClock_Config).
## Step 5: 

In your code, call the `RTC_SetTime()` function to set the RTC time. The function takes the `RTC_HandleTypeDef` structure and three parameters for hours, minutes, and seconds. The function returns a `HAL_StatusTypeDef` value indicating the success or failure of the operation.

```c
    uint8_t hours = 12;
    uint8_t minutes = 30;
    uint8_t seconds = 0;
    HAL_StatusTypeDef status = RTC_SetTime(&hrtc, hours, minutes, seconds);
    if (status != HAL_OK) {
        // Handle error
    }
```

## Step 6: 

In your code, call the `RTC_GetTime()` function to get the RTC time. The function takes the `RTC_HandleTypeDef` structure and three pointers to `uint8_t` variables for hours, minutes, and seconds. The function returns a `HAL_StatusTypeDef` value indicating the success or failure of the operation.

```c
    uint8_t hours, minutes, seconds;
    HAL_StatusTypeDef status = RTC_GetTime(&hrtc, &hours, &minutes, &seconds);
    if (status != HAL_OK) {
        // Handle error
    }

```

## Step 7:

In your code, call the `RTC_SetDate()` function to set the RTC date.

```c
uint8_t day = 11;
uint8_t month = 5;
uint8_t year = 23; // It's usually the year minus 2000.

RTC_SetDate(&hrtc, day, month, year);
```
Now, the RTC date is set to 11th of May, 2023.

## Step 8:

In your code, call the `RTC_GetDate()` function to get the RTC date. You can retrieve the date using `RTC_GetDate` as follows:

```c
uint8_t day;
uint8_t month;
uint8_t year;

RTC_GetDate(&hrtc, &day, &month, &year);

printf("Current date: %02d-%02d-%02d\n", day, month, year + 2000); // Adding 2000 to get the full year.

```

## Step 9: 

Use the values of the `hours`, `minutes`, `seconds`,`day` ,`month`,`year`variables as needed in your program.

Note: The RTC module needs an external battery to retain the time when the device is powered off. The battery must be connected to the Vbat pin of the STM32 microcontroller. An external battery is not used in our setup so the time needs to be reset every time the STM32 goes off. However an external battery can be implemented to overcome this.

## Example:
Below is an example:
```c
    #include "rtc.h"

int main(void) {
    RTC_HandleTypeDef hrtc;
    uint8_t hours = 12;
    uint8_t minutes = 30;
    uint8_t seconds = 0;
    HAL_StatusTypeDef status = RTC_SetTime(&hrtc, hours, minutes, seconds);
    if (status != HAL_OK) {
        // Handle error
    }

    uint8_t read_hours, read_minutes, read_seconds;
    status = RTC_GetTime(&hrtc, &read_hours, &read_minutes, &read_seconds);
    if (status != HAL_OK) {
        // Handle error
    }
 
   uint8_t day = 11;
   uint8_t month = 5;
   uint8_t year = 23; 
   RTC_SetDate(&hrtc, day, month, year);
 
   uint8_t day;
   uint8_t month;
   uint8_t year;

   RTC_GetDate(&hrtc, &day, &month, &year);

    // Use the read hours, minutes and seconds values and the date values
    // ...

    while (1) {
        // Main loop
    }
}

```

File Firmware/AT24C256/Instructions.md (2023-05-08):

# EEPROM Library Integration Guide

This guide provides instructions on how to integrate the EEPROM library into your STM32 project using STM32Cube IDE or any other compatible IDE.

## Step 1: Download the library files

Download the following EEPROM library files:

1. `EEPROM.h` - The header file containing the function prototypes and necessary definitions.
2. `EEPROM.c` - The source file containing the function implementations.

## Step 2: Add the library files to your project

Follow these steps to add the EEPROM library files to your project:

### STM32Cube IDE

1. In STM32Cube IDE, open your STM32 project.
2. Navigate to the project tree in the "Project Explorer" tab.
3. Place the `EEPROM.h` file into the "Inc" folder (or the folder where header files are stored in your project).
4. Place the `EEPROM.c` file into the "Src" folder (or the folder where source files are stored in your project).

### Other IDEs

1. Open your STM32 project in the IDE you are using.
2. Place the `EEPROM.h` file in the folder where header files are stored in your project (usually an "include" or "inc" folder).
3. Place the `EEPROM.c` file in the folder where source files are stored in your project (usually a "source" or "src" folder).

## Step 3: Include the library header in main.c

In the `main.c` file of your project, add the following include statement at the beginning of the file, along with other include statements:

```c
#include "EEPROM.h"
```

## Step 4: Usage Examples

ere are some examples of how to use the EEPROM library in your STM32 project:

### Write data to EEPROM
 ```c
 uint8_t data_to_write[] = "Hello, EEPROM!";
EEPROM_Write(0, 0, data_to_write, sizeof(data_to_write));
```

### Read data from EEPROM
```c
uint8_t read_buffer[16];
EEPROM_Read(0, 0, read_buffer, sizeof(read_buffer));
```

### Erase a page in EEPROM

```c
EEPROM_PageErase(2);
```

### Comprenhensive example on how to use it in main.c

```c
#include "main.h"
#include "EEPROM.h"

I2C_HandleTypeDef hi2c1;

void SystemClock_Config(void);
static void MX_GPIO_Init(void);
static void MX_I2C1_Init(void);

int main(void)
{
    HAL_Init();
    SystemClock_Config();

    MX_GPIO_Init();
    MX_I2C1_Init();

    // Write data to EEPROM
    uint8_t data_to_write[] = "Hello, EEPROM!";
    EEPROM_Write(0, 0, data_to_write, sizeof(data_to_write));

    // Read data from EEPROM
    uint8_t read_buffer[16];
    EEPROM_Read(0, 0, read_buffer, sizeof(read_buffer));

    // Write a float number to EEPROM
    float number_to_write = 3.14159265;
    EEPROM_Write_NUM(1, 0, number_to_write);

    // Read a float number from EEPROM
    float read_number;
    read_number = EEPROM_Read_NUM(1, 0);

    // Erase a page in EEPROM
    EEPROM_PageErase(2);

    while (1)
    {
        // Main loop
    }
}

void SystemClock_Config(void)
{
    // System clock configuration code...
}

static void MX_GPIO_Init(void)
{
    // GPIO initialization code...
}

static void MX_I2C1_Init(void)
{
    // I2C1 initialization code...
}
```

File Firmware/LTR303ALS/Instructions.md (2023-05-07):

# LTR-303ALS Ambient Light Sensor Integration Guide

This guide will help you integrate the `ltr303als.h` and `ltr303als.c` files into your STM32 project using the LTR-303ALS Ambient Light Sensor.

## Step 1: Download the library files

Download the following files:

- `ltr303als.h`
- `ltr303als.c`

## Step 2: Add the library files to your project

1. Open your STM32 project in the STM32CubeIDE or your preferred IDE.
2. Copy the `ltr303als.h` file into the `Inc` folder of your project.
3. Copy the `ltr303als.c` file into the `Src` folder of your project.

## Step 3: Include the library in your code

In the source file where you want to use the LTR-303ALS library (usually `main.c`), add the following line at the beginning of the file:

```c

#include "ltr303als.h"
```

## Step 4: Initialize the sensor

Initialize the LTR-303ALS sensor by calling the `LTR303ALS_Init` function, passing a pointer to an `I2C_HandleTypeDef` structure and the desired integration time and measurement rate.

```c

I2C_HandleTypeDef hi2c1; // This should be configured and initialized using HAL

if (LTR303ALS_Init(&hi2c1, INTEGRATION_TIME, MEASUREMENT_RATE) != HAL_OK) {
    // Handle initialization error
}
```

## Step 5: Read light intensity

To read the light intensity from the sensor, call the `LTR303ALS_ReadLightIntensity` function, passing a pointer to an `I2C_HandleTypeDef` structure and pointers to two `uint16_t` variables that will store the values of channels 0 and 1.

```c

uint16_t ch0, ch1;

if (LTR303ALS_ReadLightIntensity(&hi2c1, &ch0, &ch1) != HAL_OK) {
    // Handle read error
} else {
    // Process light intensity data
}
```

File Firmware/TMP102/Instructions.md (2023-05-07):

# TMP102 Library Integration Guide

This guide provides instructions on how to integrate the TMP102 temperature sensor library into your STM32 project using STM32Cube IDE or any other compatible IDE.

## Step 1: Download the library files

Download the following TMP102 library files:

1. `tmp102.h` - The header file containing the function prototypes and necessary definitions.
2. `tmp102.c` - The source file containing the function implementations.

## Step 2: Add the library files to your project

Follow these steps to add the TMP102 library files to your project:

### STM32Cube IDE

1. In STM32Cube IDE, open your STM32 project.
2. Navigate to the project tree in the "Project Explorer" tab.
3. Place the `tmp102.h` file into the "Inc" folder (or the folder where header files are stored in your project).
4. Place the `tmp102.c` file into the "Src" folder (or the folder where source files are stored in your project).

### Other IDEs

1. Open your STM32 project in the IDE you are using.
2. Place the `tmp102.h` file in the folder where header files are stored in your project (usually an "include" or "inc" folder).
3. Place the `tmp102.c` file in the folder where source files are stored in your project (usually a "source" or "src" folder).

## Step 3: Include the library header in main.c

In the `main.c` file of your project, add the following include statement at the beginning of the file, along with other include statements:

```c

#include "tmp102.h"
```
## Step 4: Initialize the I2C interface

Before using the TMP102 sensor, you need to initialize the I2C interface. This can be done using the `HAL_I2C_Init()` function provided by the STM32 HAL library. Here's an example:

```c

I2C_HandleTypeDef hi2c1;

void SystemClock_Config(void);

int main(void) {
  // Initialize HAL and system clock
  HAL_Init();
  SystemClock_Config();

  // Initialize I2C1
  hi2c1.Instance = I2C1;
  hi2c1.Init.Timing = 0x00707CBB;
  hi2c1.Init.OwnAddress1 = 0;
  hi2c1.Init.AddressingMode = I2C_ADDRESSINGMODE_7BIT;
  hi2c1.Init.DualAddressMode = I2C_DUALADDRESS_DISABLE;
  hi2c1.Init.OwnAddress2 = 0;
  hi2c1.Init.GeneralCallMode = I2C_GENERALCALL_DISABLE;
  hi2c1.Init.NoStretchMode = I2C_NOSTRETCH_DISABLE;
  if (HAL_I2C_Init(&hi2c1) != HAL_OK) {
    Error_Handler();
  }
}
```

## Step 5: Initialize the TMP102 sensor and read Temperature Value
After initializing the I2C interface, you can now initialize the TMP102 sensor. This can be done using the TMP102_Init() function provided by the library. Here's an example:

```c

#include "tmp102.h"

I2C_HandleTypeDef hi2c1;

int main(void)
{
  HAL_Init();
  MX_I2C1_Init();
  
  // Initialize TMP102 sensor
  TMP102_Init(&hi2c1);//Use the I2C handle intiliased
  while (1)
  {
    // Read temperature value
    float temperature = TMP102_ReadTemperature(&hi2c1);
    
    // Do something with temperature value
  }
}

  ```

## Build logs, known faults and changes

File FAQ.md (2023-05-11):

## Frequently Asked Questions (FAQs)

**1. What is the Imperium Environmental Monitoring HAT?**

The Imperium Environmental Monitoring HAT is a hardware accessory designed for use with STM32 microcontrollers. It's equipped with high-precision sensors for environmental monitoring purposes, including temperature, humidity, atmospheric pressure, and light.

**2. What are the key features of the Imperium Environmental Monitoring HAT?**

The key features include high-precision sensors for temperature, humidity, atmospheric pressure, and light. It seamlessly integrates into various systems, is customizable, easily programmable for extra functionality, and is affordable and reliable.

**3. How do I get started with the Imperium Environmental Monitoring HAT?**

To start, connect it to your STM32 microcontroller using the provided pins. Download our library and follow the included instructions to begin collecting data. Detailed setup instructions can be found in our [setup guide](SESNSEHATSETUP.md).

**4. How can I customize the Imperium Environmental Monitoring HAT?**

The Imperium Environmental Monitoring HAT is easily programmable, allowing the end user to add extra functionality to suit their specific needs. The provided libraries in the firmware folder include examples of how to use the sensors.

**5. What kind of support is available for the Imperium Environmental Monitoring HAT?**

If you have any questions or issues with the Imperium Environmental Monitoring HAT, please contact our support team at imperiumuct@gmail.com.

**6. How do I set up the SENSEHAT for the first time?**

Detailed instructions for setting up the SENSEHAT for the first time can be found in our [setup guide](SESNSEHATSETUP.md). The steps include powering and setting up the SENSEHAT hardware, including the necessary libraries, and testing the libraries.

**7. What do I do if the SENSEHAT is not powering on?**

Ensure that the power source supplies at least 5V at 1A. If the LED does not light up, check your connections and try a different power source.

**8. How do I include the necessary libraries to the SENSEHAT?**

Download and include the necessary files as per the instructions in our [setup guide](SESNSEHATSETUP.md). Each sensor has specific instructions for downloading and including the necessary files.

**9. What if I encounter problems while setting up the SENSEHAT?**

Watch the video on [How to setup SENSEHAT](link_to_video). If you still encounter issues, feel free to contact our support team.

**10. What does the Imperium Environmental Monitoring HAT cost?**

For pricing details, please refer to our official sales page or contact our sales team directly.

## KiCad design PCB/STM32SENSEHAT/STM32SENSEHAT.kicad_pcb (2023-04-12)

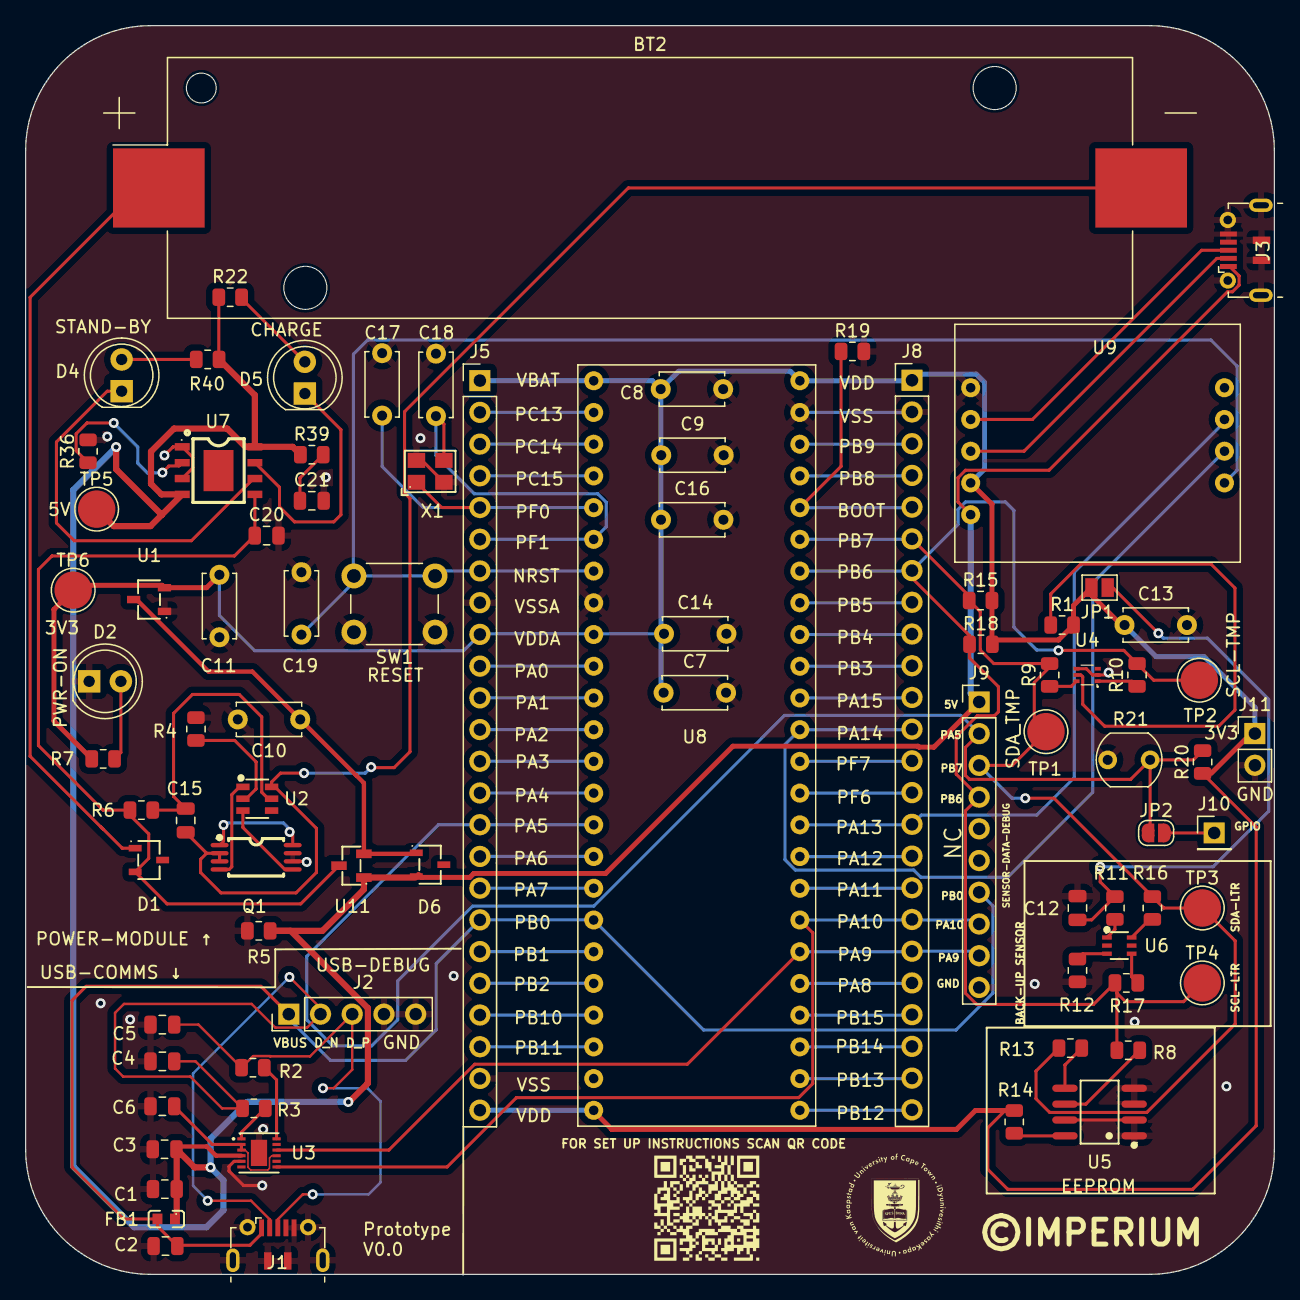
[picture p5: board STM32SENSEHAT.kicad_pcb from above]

Board: 2 copper layers, 100.0 x 100.0 mm, 82 parts (0 on the bottom side), 78 nets.

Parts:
BT2: Battery_Cell; BatteryHolder_Keystone_1042_1x18650
C1, C6, C15: 100nF; C_0805_2012Metric
C2: 10nF; C_0805_2012Metric
C3: 4.7uF; C_0805_2012Metric
C4, C5: 47pF; C_0805_2012Metric
C7, C10, C11: 1uF; C_Disc_D5.0mm_W2.5mm_P5.00mm
C8, C9, C19: 100nF; C_Disc_D5.0mm_W2.5mm_P5.00mm
C12: 1uF; C_0805_2012Metric
C13, C14: 10nF; C_Disc_D5.0mm_W2.5mm_P5.00mm
C16: 4.7uF; C_Disc_D5.0mm_W2.5mm_P5.00mm
C17, C18: 10pF; C_Disc_D5.0mm_W2.5mm_P5.00mm
C20, C21: 10uF; C_0805_2012Metric
D1, D6: D_Schottky; SOT-23-3_L3.0-W1.7-P0.95-LS2.9-BR
D2, D4, D5: LED; LED_D5.0mm
FB1: FerriteBead; L0603
J1, J3: USB_B_Micro; USB_Conn_JLC_LCSC_C404969
J2: Conn_01x05_Pin; PinHeader_1x05_P2.54mm_Vertical
J5, J8: Conn_01x24_Pin; PinHeader_1x24_P2.54mm_Vertical
J9: Conn_01x10_Pin; PinHeader_1x10_P2.54mm_Vertical
J10: Conn_01x01_Pin; PinHeader_1x01_P2.54mm_Vertical
J11: Conn_01x02_Pin; PinHeader_1x02_P2.54mm_Vertical
JP1: SolderJumper_2_Open; SolderJumper-2_P1.3mm_Open_Pad1.0x1.5mm
JP2: SolderJumper_2_Open; SolderJumper-2_P1.3mm_Open_RoundedPad1.0x1.5mm
Q1: FS8205A; TSSOP-8_L4.4-W3.0-P0.65-LS6.4-BL
R1, R8, R9, R10, R11, R12, R13, R14, R16, R17, R39: 0R; R_0805_2012Metric
R2, R3: 27R; R_0805_2012Metric
R4, R7, R22, R40: 1k0; R_0805_2012Metric
R5, R19, R20, R36: 10k; R_0805_2012Metric
R6: 100R; R_0805_2012Metric
R15, R18: 4k7; R_0805_2012Metric
R21: LDR07; R_LDR_5.1x4.3mm_P3.4mm_Vertical
SW1: SW_Push; SW_PUSH_6mm
TP1, TP2, TP3, TP4, TP5, TP6: TestPoint; TestPoint_Pad_D3.0mm
U1: MCP1700x-330xxTT; SOT-23-3_L2.9-W1.6-P1.90-LS2.8-BR
U2: DW01A; SOT-23-6_L2.9-W1.6-P0.95-LS2.8-BL
U3: FT234XD-R; DFN-12_L3.0-W3.0-P0.45-BL-EP
U4: TMP102xxDRL; SOT-563_L1.6-W1.2-P0.50-LS1.6-BR
U5: CAT24C256; SOIC-8_L4.9-W3.9-P1.27-LS6.0-BL
U6: LTR-303ALS-01; SOT-363_L2.0-W1.3-P0.65-LS2.1-BL
U7: TP4056; ESOP-8_L4.9-W3.9-P1.27-LS6.0-BL-EP
U8: STM32F051C6T6
U9: STLINK_UCT
U11: AO3401A_C306862; SOT-23-3_L2.9-W1.3-P1.90-LS2.4-BR
X1: XXDCELNANF-8MHZ; OSC-SMD_4P-L3.2-W2.5-BL

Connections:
3V3: C7.1, C8.1, C9.1, C11.1, C13.1, C14.1, C16.1, J5.1, J5.9, J5.24, J8.1, J11.1, JP1.2 (B), R1.2, R7.1, R14.1, R15.2, R18.2, R20.1, TP6.1, U1.2 (VO), U8.1 (VBAT), U8.9 (V+), U8.24 (V+), U8.48 (V+), U9.2 (V_Target)
5VUSB: C1.1, C3.1, D6.2 (A), FB1.1, J3.1 (VBUS), J9.1, R5.1, R22.1, R39.1, R40.1, TP5.1, U3.4 (VCC), U7.4 (VCC), U7.8 (CE), U9.1 (5V_USB), U11.1 (G)
/MCU MODULE/BOOT: J8.5, R19.1, U8.44 (BOOT)
/MCU MODULE/NRST: C19.1, J5.7, SW1.2, U8.7 (NRST), U9.6 (T_NRST)
/MCU MODULE/PA0: J5.10, U8.10 (PA0)
/MCU MODULE/PA1: J5.11, U8.11 (PA1)
/MCU MODULE/PA2: J5.12, U8.12 (PA2)
/MCU MODULE/PA3: J5.13, U8.13 (PA3)
/MCU MODULE/PA4: J5.14, U8.14 (PA4)
/MCU MODULE/PA5: J5.15, J9.2, JP2.1 (A), R20.2, R21.1, U8.15 (PA5)
/MCU MODULE/PA6: J5.16, U8.16 (PA6)
/MCU MODULE/PA7: J5.17, U8.17 (PA7)
/MCU MODULE/PA8: J8.20, U8.29 (PA8)
/MCU MODULE/PA9: J8.19, J9.9, U3.10 (RXD), U8.30 (PA9)
/MCU MODULE/PA10: J8.18, J9.8, U3.7 (TXD), U8.31 (PA10)
/MCU MODULE/PA11: J8.17, U8.32 (PA11)
/MCU MODULE/PA12: J8.16, U8.33 (PA12)
/MCU MODULE/PA13: J8.15, U8.34 (PA13), U9.8 (T_SWDIO)
/MCU MODULE/PA14: J8.12, U8.37 (PA14), U9.7 (T_SWCLK)
/MCU MODULE/PA15: J8.11, U8.38 (PA15)
/MCU MODULE/PB0: C2.1, FB1.2, J1.1 (VBUS), J2.1, J5.18, J9.7, U8.18 (PB0)
/MCU MODULE/PB1: J5.19, U8.19 (PB1)
/MCU MODULE/PB2: J5.20, U8.20 (PB2)
/MCU MODULE/PB3: J8.10, U8.39 (PB3)
/MCU MODULE/PB4: J8.9, U8.40 (PB4)
/MCU MODULE/PB5: J8.8, U8.41 (PB5)
/MCU MODULE/PB6: J8.7, J9.4, R8.2, R10.2, R17.2, R18.1, TP2.1, TP4.1, U8.42 (PB6)
/MCU MODULE/PB7: J8.6, J9.3, R9.2, R13.1, R15.1, R16.2, TP1.1, TP3.1, U8.43 (PB7)
/MCU MODULE/PB8: J8.4, U8.45 (PB8)
/MCU MODULE/PB9: J8.3, U8.46 (PB9)
/MCU MODULE/PB10: J5.21, U8.21 (PB10)
/MCU MODULE/PB11: J5.22, U8.22 (PB11)
/MCU MODULE/PB12: J8.24, U8.25 (PB12)
/MCU MODULE/PB13: J8.23, U8.26 (PB13)
/MCU MODULE/PB14: J8.22, U8.27 (PB14)
/MCU MODULE/PB15: J8.21, U8.28 (PB15)
/MCU MODULE/PC13: J5.2, U8.2 (PC13)
/MCU MODULE/PC14: J5.3, U8.3 (PC14)
/MCU MODULE/PC15: J5.4, U8.4 (PC15)
/MCU MODULE/PF0: C17.1, J5.5, U8.5 (PF0), X1.1 (OE#)
/MCU MODULE/PF1: C18.1, J5.6, U8.6 (PF1), X1.3 (OUT)
/MCU MODULE/PF6: J8.14, U8.35 (PF6)
/MCU MODULE/PF7: J8.13, U8.36 (PF7)
/MCU MODULE/USB_DN: C4.1, J1.2 (D-), J2.2, R3.1
/MCU MODULE/USB_DP: C5.1, J1.3 (D+), J2.3, R2.1
/POWER MANAGEMENT MODULE/BATT+: C20.1, D1.2 (A), R6.2, U7.5 (BAT), U11.3 (D)
/POWER MANAGEMENT MODULE/LOAD_PWR: C10.1, D6.1 (K), U1.3 (VI), U11.2 (S)
/POWER MANAGEMENT MODULE/PROG: R36.1, U7.2 (PROG)
GND: C1.2, C2.2, C3.2, C4.2, C5.2, C6.2, C7.2, C8.2, C9.2, C10.2, C11.2, C12.2, C13.2, C14.2, C16.2, C17.2, C18.2, C19.2, C20.2, C21.2, D2.1 (K), J1.4 (ID), J1.5 (GND), J1.6 (Shield), J2.4, J2.5, J3.4 (ID), J3.5 (GND), J3.6 (Shield), J5.8, J5.23, J8.2, J9.10, J11.2, Q1.6, Q1.7, R4.2, R5.2, R12.1, R19.2, R21.2, R36.2, SW1.1, U1.1 (GND), U3.5 (GND), U3.13 (GND), U4.2 (GND), U4.4 (ADD0), U5.1 (A0), U5.2 (A1), U5.3 (A2), U5.4 (GND), U5.7 (WP), U7.1 (TEMP), U7.3 (GND), U8.8 (GND), U8.23 (GND), U8.47 (GND), U9.5 (GND), X1.2 (GND), X1.4 (GND)
unnamed: BT2.1 (+), D1.1 (K)
unnamed: BT2.2 (-), C15.2, Q1.2, Q1.3, U2.6 (GND)
unnamed: C21.1, R39.2
unnamed: D2.2 (A), R7.2
unnamed: D4.2 (A), R40.2
unnamed: D4.1 (K), U7.6 (!STDBY)
unnamed: D5.2 (A), R22.2
unnamed: D5.1 (K), U7.7 (!CHRG)
unnamed: J3.3 (D+), U9.4 (USB_DP)
unnamed: J3.2 (D-), U9.3 (USB_DM)
unnamed: J10.1, JP2.2 (B)
unnamed: C12.1, JP1.1 (A), R11.2
unnamed: R4.1, U2.2 (CS)
unnamed: Q1.5, U2.3 (OC)
unnamed: Q1.4, U2.1 (OD)
unnamed: C15.1, R6.1, U2.5 (VDD)
unnamed: C6.1, U3.2 (~RESET#), U3.3 (3V3OUT), U3.9 (VCCIO)
unnamed: R3.2, U3.1 (USBDM)
unnamed: R2.2, U3.12 (USBDP)
unnamed: R10.1, U4.1 (SCL)
unnamed: R9.1, U4.6 (SDA)
unnamed: R1.1, U4.5 (V+)
unnamed: R8.1, U5.6 (SCL)
unnamed: R13.2, U5.5 (SDA)
unnamed: R14.2, U5.8 (VCC)
unnamed: R12.2, U6.3 (GND)
unnamed: R17.1, U6.4 (SCL)
unnamed: R16.1, U6.6 (SDA)
unnamed: R11.1, U6.1 (VDD)

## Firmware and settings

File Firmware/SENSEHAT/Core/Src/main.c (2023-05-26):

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
/* Includes ------------------------------------------------------------------*/
#include "main.h"

/* USER CODE BEGIN Includes */
#include "rtc.h"
#include "ldr.h"
#include "tmp102.h"
#include "EEPROM.h"
#include "string.h"

#include <math.h>
#include <stdbool.h>
/* USER CODE END Includes */

ADC_HandleTypeDef hadc;

I2C_HandleTypeDef hi2c1;

RTC_HandleTypeDef hrtc;

TIM_HandleTypeDef htim2;

UART_HandleTypeDef huart1;

/* USER CODE BEGIN PV */
// Change these values to set time and date each time the stm32 goes off
uint8_t hours = 14;
uint8_t minutes = 00;
uint8_t seconds = 0;
uint8_t day = 19;
uint8_t month = 5;
uint8_t year = 23;



uint8_t read_hours, read_minutes, read_seconds;
char time_string[9];

uint8_t dayread;
uint8_t monthread;
uint8_t yearread;
char date_string[11];


float light_intensity;


float temperature;


char temp_string[10];
char light_string[10];

HAL_StatusTypeDef status;


// Global variable to track the current page
uint16_t current_page = 0;

// Flag to indicate whether the EEPROM is full
bool eeprom_full = false;

//Flag to indicate whether USB is plugged
bool usb_plugged = false;

/* USER CODE END PV */

void SystemClock_Config(void);
static void MX_GPIO_Init(void);
static void MX_ADC_Init(void);
static void MX_I2C1_Init(void);
static void MX_RTC_Init(void);
static void MX_USART1_UART_Init(void);
static void MX_TIM2_Init(void);
/* USER CODE BEGIN PFP */
void read_and_transmit_all_data(void);
void read_and_store_data(void);
void check_GPIO_state(void);
/* USER CODE END PFP */

/**
  * @brief  The application entry point.
  * @retval int
  */
int main(void)
{
  /* MCU Configuration--------------------------------------------------------*/

  /* Reset of all peripherals, Initializes the Flash interface and the Systick. */
  HAL_Init();

  /* Configure the system clock */
  SystemClock_Config();

  /* Initialize all configured peripherals */
  MX_GPIO_Init();
  MX_ADC_Init();
  MX_I2C1_Init();
  MX_RTC_Init();
  MX_USART1_UART_Init();
  MX_TIM2_Init();
  /* USER CODE BEGIN 2 */

  //Set calibration constants for the LDR
  LDR_Init();

  //Set Time and Date
    status = RTC_SetTime(&hrtc, hours, minutes, seconds);

    if (status != HAL_OK) {
        // Handle error will be implemented later
    }

    RTC_SetDate(&hrtc, day, month, year);

    //Initiliaze temperature sensor
    if (TMP102_Init(&hi2c1) != HAL_OK) {
          // Handle error (e.g., turn on an LED or print a message)
    	  strcpy((char*)temp_string,"Error Tx\r\n");
      }




  /* USER CODE END 2 */

  /* Infinite loop */
  /* USER CODE BEGIN WHILE */
  while (1)
  {
	  //Back -up for demo in case interrupts dont work
	  //Remember to implement function to update the usb_plugged flag
	  check_GPIO_state();
	  if(usb_plugged){
		  HAL_Delay(30000);
		  read_and_transmit_all_data();
	  }
	  else{
		  read_and_store_data();
	  }

	  HAL_Delay(10000);







    /* USER CODE END WHILE */

    /* USER CODE BEGIN 3 */
  }
  /* USER CODE END 3 */
}

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
/* USER CODE BEGIN 4 */
/**

@brief Read and store data

This function reads the light intensity, temperature, date, and time, and stores the data in the EEPROM memory.

The data is formatted using CSV (Comma-Separated Values) format and written to the EEPROM memory.

The function checks if the EEPROM is full before performing any write operations.

@note If the EEPROM is full, the function does not perform any write operations.
*/
/*void read_and_store_data(void)
{
    // If the EEPROM is full, don't perform any write operations
    if(eeprom_full) {
        return;
    }
	  //Read Light Intensity
	  light_intensity = LDR_ReadAnalogLightIntensity(&hadc);

	  int light_whole = (int)light_intensity;
	  int light_frac = (int)(100 * (light_intensity - light_whole));
	  sprintf(light_string, "%d.%02d", light_whole, light_frac);

	  //Read Temperature
	  temperature = TMP102_ReadTemperature(&hi2c1);
	  int temp_whole = (int)temperature;
	  int temp_frac = (int)(100 * (temperature - temp_whole));
	  sprintf(temp_string, "%d.%02d", temp_whole, temp_frac);

	   //Get the date
	   RTC_GetDate(&hrtc, &dayread, &monthread, &yearread);
	   // Convert the integers to a string
	   sprintf(date_string, "%02d-%02d-%02d", dayread, monthread, yearread);

	   //Get the time
	   status = RTC_GetTime(&hrtc, &read_hours, &read_minutes, &read_seconds);
	   if (status != HAL_OK) {
	       // Handle error
	   }

	   // Convert the integers to a string
	   sprintf(time_string, "%02d:%02d:%02d", read_hours, read_minutes, read_seconds);

	    // Calculate the size of the message
	    uint16_t message_size = strlen(light_string) + strlen(temp_string) + strlen(date_string) + strlen(time_string) + 3; // 3 for the ',' separators

	    // Create a complete message string using CSV formatting
	    char message[message_size + 1]; // +1 for the null terminator
	    sprintf(message, "%s,%s,%s,%s\r\n", date_string, time_string, temp_string, light_string);


	    // Check if the message can fit into the current page. If not, go to the next page.
	    if(message_size > PAGE_SIZE) {
	        current_page++;
	    }

	    // Check if there's enough space left in the EEPROM
	    if(current_page < PAGE_NUM) {
	        // Write the message to the EEPROM
	        EEPROM_Write(current_page, 0, (uint8_t *)message, message_size);

	        // If the message size is less than the page size, the next write operation will start from where it left.
	        // Otherwise, the next write operation will start from the next page.
	        if(message_size < PAGE_SIZE) {
	            current_page += message_size / PAGE_SIZE;
	        } else {
	            current_page++;
	        }

	    } else {
	        // EEPROM is full, set the flag to prevent further writing
	        eeprom_full = true;
	    }




}*/

void read_and_store_data(void)
{
    // If the EEPROM is full, don't perform any write operations
    if(eeprom_full) {
        return;
    }
	  //Read Light Intensity
	  light_intensity = LDR_ReadAnalogLightIntensity(&hadc);

	  int light_whole = (int)light_intensity;
	  int light_frac = (int)(100 * (light_intensity - light_whole));
	  sprintf(light_string, "%d.%02d", light_whole, light_frac);

	  //Read Temperature
	  temperature = TMP102_ReadTemperature(&hi2c1);
	  int temp_whole = (int)temperature;
	  int temp_frac = (int)(100 * (temperature - temp_whole));
	  sprintf(temp_string, "%d.%02d", temp_whole, temp_frac);

	   //Get the date
	   RTC_GetDate(&hrtc, &dayread, &monthread, &yearread);
	   // Convert the integers to a string
	   sprintf(date_string, "%02d-%02d-%02d", dayread, monthread, yearread);

	   //Get the time
	   status = RTC_GetTime(&hrtc, &read_hours, &read_minutes, &read_seconds);
	   if (status != HAL_OK) {
	       // Handle error
	   }

	   // Convert the integers to a string
	   sprintf(time_string, "%02d:%02d:%02d", read_hours, read_minutes, read_seconds);

	    // Calculate the size of the message
	    //uint16_t message_size = strlen(light_string) + strlen(temp_string) + strlen(date_string) + strlen(time_string) + 20; // 20 for the 'Date: ','Time: ','Temp: ','Light: ' and '\r\n'

	    // Create a complete message string
	    //char message[message_size + 1]; // +1 for the null terminator

	    char message[64];
	    sprintf(message, "Date: %s Time: %s Temp: %s Light: %s\r\n", date_string, time_string, temp_string, light_string);

	    // Check if the message can fit into the current page. If not, go to the next page.
	    if(current_page < PAGE_NUM) {
	    	// Write the message to the EEPROM
	    	EEPROM_Write(current_page, 0, (uint8_t *)message, strlen(message));
	    	current_page++;

	    }

	    else{
	    	eeprom_full = true;
	    }

	    // Check if there's enough space left in the EEPROM
	    /*
	     * if(current_page < PAGE_NUM) {
	        // Write the message to the EEPROM
	        EEPROM_Write(current_page, 0, (uint8_t *)message, message_size);

	        // If the message size is less than the page size, the next write operation will start from where it left.
	        // Otherwise, the next write operation will start from the next page.
	        if(message_size < PAGE_SIZE) {
	            current_page += message_size / PAGE_SIZE;
	        } else {
	            current_page++;
	        }

	    } else {
	        // EEPROM is full, set the flag to prevent further writing
	        eeprom_full = true;
	    }
	     */
}




/**

@brief Read and transmit all data
This function reads all the data stored in the EEPROM memory and transmits it over UART.
It loops through all the pages of the EEPROM, reads the data from each page, and transmits it using UART communication.
There is a delay between each UART transmission to ensure proper data transmission.
@note This function assumes that the EEPROM has been filled with data and the eeprom_full flag is not checked.
      If the EEPROM is not filled with data, this function may transmit garbage values.
*/

/*void read_and_transmit_all_data(void)
{
    // If the EEPROM is not full, don't perform any read operations
    /*if(!eeprom_full) {
        return;
    }

    // Buffer to hold the data read from the EEPROM
    uint8_t data[PAGE_SIZE];

    // Loop through all pages
    for(uint16_t page = 0; page < PAGE_NUM; page++) {
        // Read data from the current page of the EEPROM
        EEPROM_Read(page, 0, data, PAGE_SIZE);

        // Transmit the data over UART
        HAL_UART_Transmit(&huart1, data, strlen((char *)data), 1000);


        // Delay between each UART transmission

        HAL_Delay(10);
    }

    //Erase everything after transmission
    for (int i=0; i<512; i++)
    {
  	  EEPROM_PageErase(i);
    }


} */


void read_and_transmit_all_data(void)
{
    // If the EEPROM is not full, don't perform any read operations
    /*if(!eeprom_full) {
        return;
    }*/

    // Buffer to hold the data read from the EEPROM
    uint8_t data[PAGE_SIZE + 1];  // +1 for the null terminator

    // Loop through all pages
    for(uint16_t page = 0; page < PAGE_NUM; page++) {
        // Read data from the current page of the EEPROM
        EEPROM_Read(page, 0, data, PAGE_SIZE);

        // Ensure that the data is null-terminated
        data[PAGE_SIZE] = '\0';

        // Transmit the data over UART
        HAL_UART_Transmit(&huart1, data, PAGE_SIZE, 1000);


        // Delay between each UART transmission
        HAL_Delay(10);
    }

    //Erase everything after transmission
    for (int i=0; i<512; i++)
    {
  	  EEPROM_PageErase(i);
    }
    eeprom_full = false;
}




/**

@brief GPIO EXTI callback function
This function is called when an EXTI interrupt event is triggered on a GPIO pin.
It specifically handles the interrupt triggered by the PB10 pin, indicating that the USB has been plugged in.
When this interrupt occurs, the function starts transmitting all the stored data over UART.
@param GPIO_Pin The GPIO pin that triggered the interrupt
*/

void HAL_GPIO_EXTI_Callback(uint16_t GPIO_Pin){
	// If The INT Source Is EXTI 10 (PB10 Pin) indicating USB has been plugged in

	if(GPIO_Pin == GPIO_PIN_2){
		//Start transmitting data
		//read_and_transmit_all_data();
		usb_plugged = true;
		HAL_GPIO_TogglePin(GPIOB, GPIO_PIN_11);


	}
}


void check_GPIO_state(void)
{
    GPIO_PinState PinState;

    // Check the state of the GPIO pin
    PinState = HAL_GPIO_ReadPin(GPIOB, GPIO_PIN_2);

    if (PinState == GPIO_PIN_SET)
    {
        // If the pin is set, then do something here
    	usb_plugged = true;
    }
    else if (PinState == GPIO_PIN_RESET)
    {
        // If the pin is reset, then do something else here
    	usb_plugged = false;
    }
}


/**
 * @brief TIM period elapsed callback function
 *
 * This function is called when the period of a TIM (Timer) peripheral has elapsed.
 * It specifically handles the callback for the timer used to track the elapsed time of 60 seconds.
 * When this callback is triggered, the function reads data from the sensors and stores it.
 */
/*void HAL_TIM_PeriodElapsedCallback(TIM_HandleTypeDef* htim)
{
	//if 60s have elapsed we read data from the sensors

	read_and_store_data();
}*/



/* USER CODE END 4 */
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


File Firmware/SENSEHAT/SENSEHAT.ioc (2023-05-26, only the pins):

Mcu.UserName=STM32F051C6Tx
PA10.Signal=USART1_RX
PA5.Signal=ADC_IN5
PA9.Signal=USART1_TX
PB2.Signal=GPIO_Input
PB6.Signal=I2C1_SCL
PB7.Signal=I2C1_SDA
PC14-OSC32_IN.Signal=RCC_OSC32_IN
PC15-OSC32_OUT.Signal=RCC_OSC32_OUT
PF0-OSC_IN.Signal=RCC_OSC_IN
PF1-OSC_OUT.Signal=RCC_OSC_OUT

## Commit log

2023-02-24 BME280 Sensor Datasheet possible sensor selection
2023-03-04 Sense hat Schematic First Iteration
    [STM32SENSEHAT.kicad_pcb, STM32SENSEHAT.kicad_sch, mcu.kicad_sch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]
2023-03-04 rework of top level sheet, MCU, power and sensor sheet
    [STM32SENSEHAT.kicad_sch, mcu.kicad_sch, power.kicad_sch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]
2023-03-04 BOM generated
    [STM32SENSEHAT.csv]
2023-03-04 Modified the connector symbol for STM32 from 66 pins to 48 pins
    [mcu.kicad_sch]
2023-03-05 Add STM32SENSEHAT, power, sensor, and mcu schematic files
    [STM32SENSEHAT.kicad_sch, mcu.kicad_sch, power.kicad_sch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]
2023-03-05 Removed the extra sensor, Modified BME280 interfacing and FTDI UART pins. Added Manual Reset to MCU and configured BOOT pin
    [STM32SENSEHAT.kicad_sch, mcu.kicad_sch, power.kicad_sch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]
2023-03-05 Upload Sensehat BOM File
    [SENSEHATBOM.xlsx]
2023-03-06 Add STM32SENSEHAT, power, sensor, and mcu schematic file
    [STM32SENSEHAT.kicad_sch, power.kicad_sch, sensor.kicad_sch]
2023-03-06 Rectified management spelling, added notes to sensor module and removed extra sensor's I2C pin
    [sensor.kicad_sch]
2023-03-08 Revised schematics. Moved USB and EEPROM sub modules to MCU sheet and and rectified the top sheet accordingly
    [STM32SENSEHAT.kicad_sch, mcu.kicad_sch, power.kicad_sch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]
2023-03-08 Added I2C,GPIO ports for the back up sesnors to the top level sheet
    [STM32SENSEHAT.kicad_sch]
2023-03-08 Added extra set of male pin headers
    [mcu.kicad_sch]
2023-03-08 Added Battery Volatge Sesnsing capability
    [power.kicad_sch]
2023-03-08 Added an extra back up sensor(#LTR-303 ALS-01),Test points for I2C SDA and SCL and solder jumpers
    [sensor.kicad_sch]
2023-03-08 Removed STM32SENSEHAT-backups/STM32SENSEHAT-2023-03-04_114006.zip
2023-03-08 Removed STM32SENSEHAT-backups/STM32SENSEHAT-2023-03-04_115300.zip
2023-03-10 Protectuion features added to all schematica
    [STM32SENSEHAT.kicad_sch, mcu.kicad_sch, power.kicad_sch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]
2023-03-11 Schematics reviewed
    [mcu.kicad_sch, power.kicad_sch, sensor.kicad_sch]
2023-03-11 Schematics review top sheet
    [STM32SENSEHAT.kicad_sch]
2023-03-12 Added footprints to the components but still pending review by Rumbizdai and Phomolo
    [STM32SENSEHAT.kicad_pcb, mcu.kicad_sch, power.kicad_sch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]
2023-03-25 Rework of Power,MCU and Sensor Schematic
    [STM32SENSEHAT.kicad_pcb, STM32SENSEHAT.kicad_sch, mcu.kicad_sch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]
2023-03-25 PCB draft
    [STM32SENSEHAT.kicad_pcb, mcu.kicad_sch, power.kicad_sch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]
2023-03-26 Changed the footprint of cpacitors C10 and C11 to C_disc"
    [STM32SENSEHAT.kicad_pcb, power.kicad_sch]
2023-03-27 Changed TMP102 capacitor footprint to ceramic
    [sensor.kicad_sch]
2023-03-27 OScillator added
    [STM32SENSEHAT.kicad_pcb, mcu.kicad_sch]
2023-03-27 Changed the value of the oscillator's capcitors to match the specified value in the datasheet
    [mcu.kicad_sch]
2023-03-27 Added capacitor paralle to NRST switch to mtigate parasitic effects
    [mcu.kicad_sch]
2023-03-27 Uploaded datasheets for chips in schematic
2023-03-28 New PCB with tracks laid
    [STM32SENSEHAT.kicad_pcb]
2023-03-28 Slight PCB changes
    [STM32SENSEHAT.kicad_pcb]
2023-03-28 Added a poer indicator LED and rectified NRST parastic capacitance
    [mcu.kicad_sch, power.kicad_sch]
2023-03-28 Updated PCB with latest changes
    [STM32SENSEHAT.kicad_pcb]
2023-03-28 Final draft pending review
    [STM32SENSEHAT.kicad_pcb]
2023-03-29 Gerber files and postion files generated
    [FINALBOM DRAFT - Sheet2.csv, bom.csv, designators.csv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]
2023-03-29 JLC ready BOm draft
    [Finalbom.csv, Finalbom.xls]
2023-03-31 Changed the QR Code on PCB
    [STM32SENSEHAT.kicad_pcb, mcu.kicad_sch]
2023-03-31 Changed the Oscillator to C518154 cause of low stock
    [Finalbom.csv]
2023-04-01 Deleted old production files
    [FINALBOM DRAFT - Sheet2.csv, bom.csv, designators.csv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]
2023-04-01 updated PCB
    [STM32SENSEHAT.kicad_pcb, bom.csv, designators.csv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]
2023-04-03 Cleaned up Production Files
    [GROUP 7 POSITION FILE.csv, GROUP7 BOM.csv, bom.csv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]
2023-04-03 Deleted production files
    [bom.csv, designators.csv, positions.csv]
2023-04-04 Rectified error on FS8205A and AO3401
    [GROUP7 BOM.csv]
2023-04-12 Added Justin's Feedback
    [STM32SENSEHAT.kicad_pcb, mcu.kicad_sch, power.kicad_sch]
2023-04-13 Update GROUP7 BOM.csv
    [GROUP7 BOM.csv]
2023-04-13 Modified production files
    [GROUP7 BOM.csv, GROUP7 POSITION FILE.csv, bom.csv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]
2023-04-13 Modified BOM
    [GROUP7 BOM.csv]
2023-04-13 Modified production files gerber files
2023-05-06 Added Library files for LDR but yet to tested
    [bom.csv]
2023-05-07 Sensor data and rtc libraries uodate
2023-05-08 Deleted information on the humidity and temperature sensor
2023-05-08 Added the initial drafts for the code dcoumentation for the sensor libraries
2023-05-08 Rectified error on floattobytes function
    [EEPROM.c]
2023-05-09 Deleted CAD and Simulation
2023-05-10 Delete 20230509_231036[1].jpg
    Replacing the board image
2023-05-10 Add files via upload
    STM32 board image
2023-05-10 Delete STM32_board.jpg
    Replacing STM32 board the image with edited one
2023-05-10 Add files via upload
    Edited STM32 board image
2023-05-10 Delete STM32 board.png
    Deleted old STM32 board image
2023-05-10 Add files via upload
    New STM32 board image (jpg file)
2023-05-11 Linked the STM32 Peripheral setup file
2023-05-13 Added link to the stm32sensehat driver
2023-05-26 Last change
    [power.kicad_sch]

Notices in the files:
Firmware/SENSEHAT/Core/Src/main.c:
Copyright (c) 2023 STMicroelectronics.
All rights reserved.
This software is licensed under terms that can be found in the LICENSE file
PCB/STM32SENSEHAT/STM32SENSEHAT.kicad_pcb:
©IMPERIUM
